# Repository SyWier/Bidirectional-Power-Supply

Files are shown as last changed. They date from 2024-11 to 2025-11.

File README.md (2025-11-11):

# Bidirectional-Power-Supply
Development of a bidirectional DC/DC power supply for battery applications.

The designed **developement** board is a **BUCK/BOOST converter**, based on the direction of the power flow. This enables us to charge a battery with voltage reduction or create an uninterrupted voltage output with voltage boost.

The developement board is easily configurable through serial communication, have test points for all the important signals and includes feedback LEDs.

## Directories
- Altium: **Altium** project of the hardware.
- CSS: **Code Composer Studio** project and other tools to flash the microcontroller



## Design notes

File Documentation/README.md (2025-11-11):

# Documentation

This folder contains the documentation for my **thesis project**. The files describe the device's specifications, development flow, and configuration. All documents are written in Hungarian.

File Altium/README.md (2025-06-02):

# Hardware

PCB designed in Altium Designer (version 24.9.1)

Specifications:
- Input: 5V, 3A 
- Output: 5V, 3A
- Battery: 3.7V, 8A
- Target voltage ripple: 0.2%
- Target current ripple: 1%
- Switching frequency: 100kHz

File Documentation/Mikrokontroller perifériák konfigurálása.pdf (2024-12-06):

# 1 Mikrokontroller perifériák programozása

## 1.1 Fejlesztő környezet

### 1.1.1 Code Composer Studio + Sysconfig

A mikrokontroller programozásához a Code Composer Studio-t használom, mely

kifejezetten a Texas Instruments által készített mikrokontrollerekhez lett készítve, így ezeket natívan

támogatja.

A Code Composer Studio ezen kívül alapértelmezetten tartalmazza a Sysconfig nevű

konfigurációs eszközt, melynek a segítségével egy grafikus felületen tudjuk konfigurálni a

perifériákat.

Help: C28x Academy (https://dev.ti.com/tirex/explore/node?node=A__AEIJm0rwIeU.2P1OBWwlaA__C28X-ACADEMY__1sbHxUB__LATEST)

### 1.1.2 C2000Ware

A mikrokontrollerekhez tartozó SDK¹
-t letölthetjük a C2000Ware telepítésével. Ez

tartalmazza a C2000-es családba tartozó mikrokontrollerek driverjeinek könyvtárát, illetve példákat

is tartalmaz a különféle mikrokontrollerekhez.

1 SDK = Software Development Kit

Mikrokontroller programozás

## 1.2 Konfiguráció sysconfig segítségével

A fejlesztés során a perifériák felprogramozásához részletes leírást találunk a

mikrokontroller adatlapjában, ahol láthatjuk, hogy mely regiszterek mely értékei mit jelentenek.

Ezek a regiszterek a fejlesztőkörnyezetben az SDK segítségével adatstruktúrákként jelennek meg.

A periféria felélesztéséhez ezeket a struktúrákat kel kitölteni a kívánt viselkedés elérésének

érdekében.

Ez a folyamat azonban hosszadalmas és sok adatlapolvasást igényel. A fejlesztés

felgyorsításának érdekében készült a sysconfig nevű konfigurációs eszköz, ahol egy grafikus

felületen be tudjuk állítani a perifériát és ez alapján kódot generál nekünk.

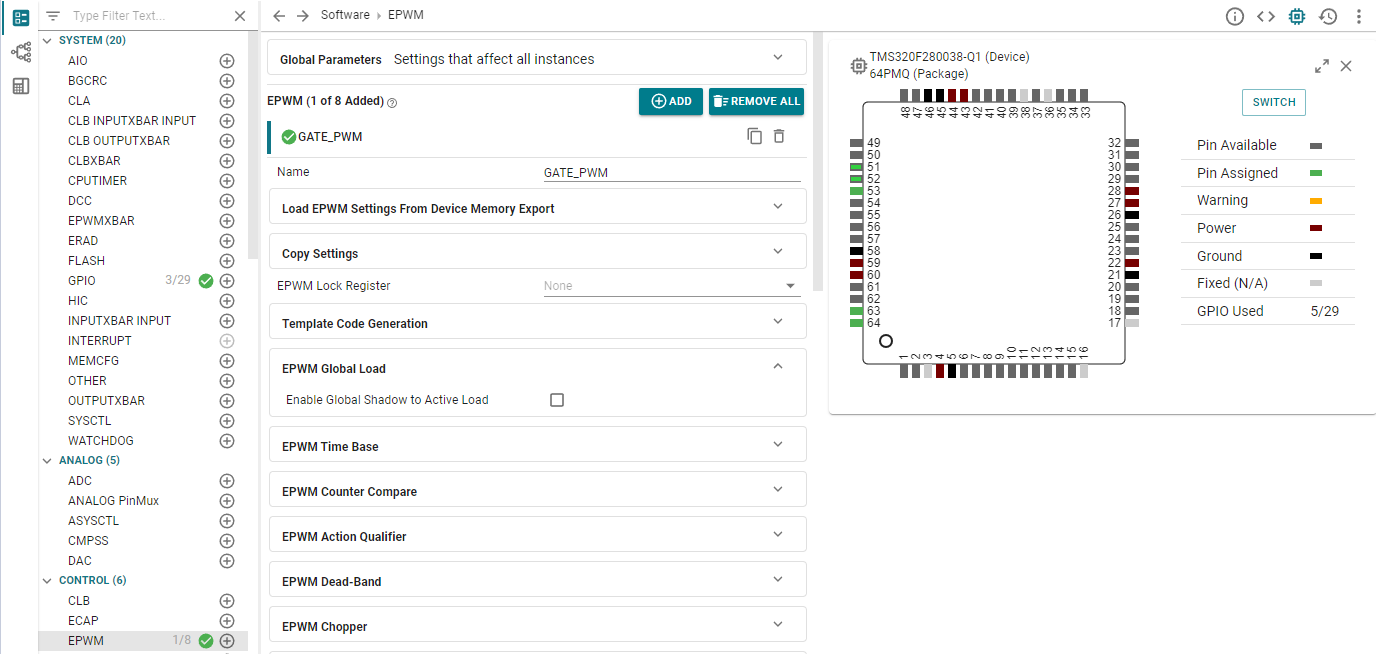
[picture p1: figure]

1-1. Sysconfig konfigurációs interfész

Source: C2000 SysConfig (spracx3.pdf) (https://www.ti.com/lit/an/spracx3/spracx3.pdf?ts=1731794783741)

## 1.3 Program feltöltése a mikrokontrollerre

### 1.3.1 Boot mode kiválasztása

Én a soros kommunikáció (SCI) mellett döntöttem, mivel ehhez elég egy USB-UART

átalakító, melyet olcsón és könnyedén a mikrokontroller mellé lehetett integrálni. A soros

kommunikáció használatához a táblázat alapján látni lehet, hogy a GPIO24-et alacsonyra kell

húzni, míg a GPIO32-őt magasra. Mivel alapértelmezetten mind a kettő GPIO értéke magas, hogy

flash-ről bootoljon, így célszerűen elég csak a GPIO24-et lehúzni alacsony szintre.

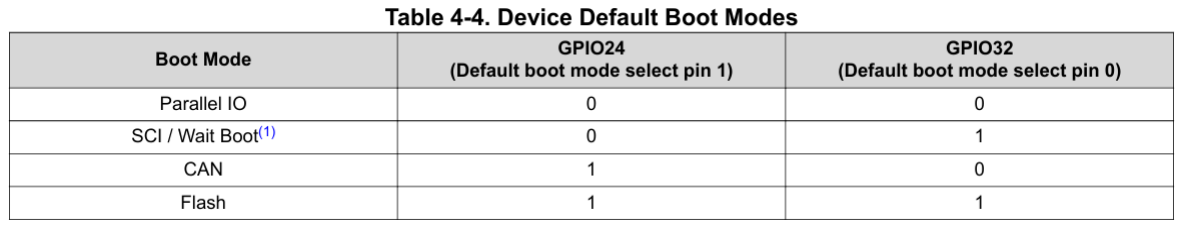
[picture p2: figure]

1-2. A mikrokontroller boot módja a kiválasztott pinek alapján

1-3. Boot 1 pin alacsonyra húzása jumper segítségével

### 1.3.2 Kód feltöltésének folyamata¹

Amikor a mikrokontroller kommunikációs perifériáit használjuk, az nagyon egyszerűen tud a

RAM-ba adatot, kódot tölteni. Viszont ez még nincs benne a nem felejtő memóriában. A két

memória közötti különbséget a flash kernel fogja áthidalni. Ez egy olyan program részlet, melyet a

kommunikáció elején a RAM-ba töltünk és a RAM-ból fogjuk futtatni. Innentől kezdve a

kommunikáció többi csomagját már a Flash memóriába fogjuk tölteni. A mikrokontrollert újraindítva

a „Flash” boot mode-ban már az így letöltött kódunk fog elindulni.

1-4. Program feltöltésének folyamatábrája

Az F280038-as mikrokontrollerhez a B típusú Flash Kernel fog tartozni, ami nem csak a

kódot fogja betölteni a flash memóriába, de még visszajelzést is ad a felhasználó fele. Ezután vár egy ’a’/’A’ karakterre. A kommunikáció megkezdésekor auto-baud segítségével autómatikusan

kiválasztódik a legmagasabb baud rate és a letöltés megkezdődik a flash memóriába.

A flash kernelt a mikrokontrollerhez tartozó driverlib-ben fogjuk megtalálni. Itt a példák

között található flash mappában megtaláljuk az SCI-hez tartozó kernel kódják, melyet lefordítva

megkapjuk a <kernel>.txt fájlt.

### 1.3.3 Alkalmazás a program feltöltéséhez

A mikrokontrollerre egy .out típusú hex fájlt kell feltölteni. Amikor CSS-ben lefordítjuk a

programunkat, a build mappában létre is fog jönni egy ilyen fájl. Ezt a fájlt a

serial_flash_programmer nevű parancssoros alkalmazásból tudjuk feltölteni a mikrokontrollerre.

Alapértelmezetten a C2000Ware SDK-ban az alábbi útvonalon lehet megtalálni:

C2000Ware_x_xx_xx_xx > utilities > flash_programmers > serial_flash_programmer

Az alkalmazás számára meg kell mondanunk minden szükséges paramétert ami

szükséges a mikrokontroller programozásához:

- -d <device>: The name of the device to connect and load to: F28003x
- -k <file>: The file name for the CPU1 flash kernel: flash_kernel_ex3_sci_flash_kernel.txt
- -a <file>: The application file name to download: UPS.out
- -p COM<num>: Set the COM port to be used for communications: eg. COM10
- -b <num>: Set the baud rate for the COM port: eg. 115200

A teljes paraméter lista így fog kinézni:

serial_flash_programmer.exe -d f28003x -k flash_kernel_ex3_sci_flash_kernel.txt -a UPS.hex

-p COM10 -b 115200

## 1.4 PWM jel előállítása

Az ePWM, vagyis enchanced pulse width modulator (impulzus-szélesség moduláció)

segítségével négyszögjeleket állíthatunk elő a buck-boost konverterünkben található MOSFET-ek

vezérlésére. A mikrokontrolleren belül ezen a perifériák párban állnak rendelkezésre (A modul és B

modul), melyek egymásnak az inverz jelét állítják elő. Ennek a segítségével könnyedén

vezérelhetjük az átalakítónkat.

Az ePWM generátor egy számláló segítségével állítja elő a négyszögjelünket. A számláló

minden órajel ciklusra megváltoztatja az értékét (ez lehet felfelé, lefelé, illetve fel-le számlálás. A

számláló maximális értékét meghatározva kapjuk meg a pulzusunk periódus idejét. A kitöltési

tényező meghatározásához szükségünk van egy komperálási szintre is, melynek az értéke esetén

meg tudjuk változtatni a jelünket.

Az ePWM-ből képesek vagyunk különböző eseményeket is elindítani, például a periódus

elérésekor, a számláló null értéke esetén, vagy valamely komperálási szint elérésekor. Ez

számunkra hasznos lesz az analóg mintavételezéshez, hogy mindig a jel közepén vegyünk mintát.

Source: C2000 ePWM Developer’s Guide (sprad12a.pdf) (https://www.ti.com/lit/an/sprad12a/sprad12a.pdf?ts=1732109075007)

### 1.4.1 ePWM modul

### 1.4.1.1 Frekvencia beállítása

A PWM jel előállításához szükségünk lesz a periódusidő kiszámolására is. Ennek a

kiszámolásához szükségünk van az ePWM modul órajelének meghatározására. Ez jelen esetben,

mivel az órajelünket nem osztjuk le, meg fog egyezni a rendszer órajelével (SYSCLK), vagyis

120MHz lesz.

Ez alapján a paraméterek a következőek:

TBCLK² = 120MHz => TTBCLK = 8.33ns

Határozzuk meg a MOSFET-ek kapcsolási sebességét (100kHz):

TPWM =

1

FPWM

=

1
100kHz = 10us

A számláló a TBPRD³ értékig fog számolni, így a periódusidő is ettől fog függeni. Fel vagy

lefelé számolás esetén más képleteket kell figyelembe vennünk, mint fel és lefelé számolás esetén,

mivel olyankor kétszer olyan hosszú a tartomány.

2 TBCLK = time-base clock
3 TBPRD = time-base period

Fel vagy lefelé számolás:

### TPWM = (TBPRD + 1)TTBCLK

Fel és lefelé számolás:

### TPWM = 2 ∗ TBPRD ∗ TTBCLK

A jelünket szeretnénk mintavételezni is, amit érdemes a jel közepénél megtenni. Erre

érdemes háromszögjelet választani, vagyis felfelé és lefelé számolni, mivel ilyenkor tudunk a

számláló ZRO⁴ és PRD⁵ értékénél mintavételezést indítani. Ez azért nagyon hasznos nekünk, mivel

a CMPA érték megváltoztatása, vagyis a kitöltési tényező megváltoztatása esetén is a jel közepénél

fogunk mintát venni, így azt nem kell megváltoztatni.

TBPRD =

TPWM

2 ∗ TTBCLK

=

10us
2 ∗ 8.33ns

= 600

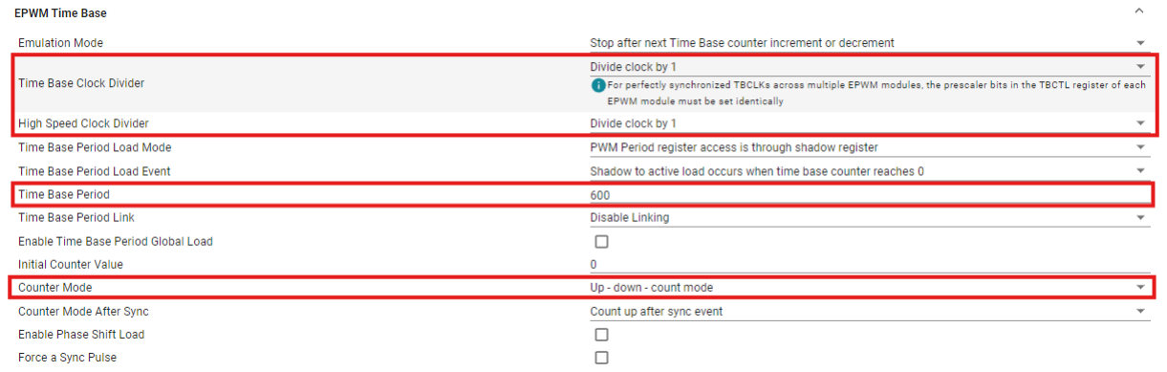
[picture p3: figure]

Frekvencia beállítására sysconfig segítségével.

### 1.4.1.2 Szinkonizáció a PWM jelek között

Mivel a mikrokontroller teljesítményelektronikák vezérlésére készült, így több beépített

funkciót is tartalmaz ezek támogatására. Egyik ilyen funkció, hogy tudjuk szinkronizálni a jeleinket,

ami akkor nagyon lényeges, ha a jeleink között fáziseltérés van, amit tartani is szeretnénk (például

egy háromfázisú inverternél). Jelen esetben csak egy darab PWM jelünk van, így csak arra kell

figyelni, hogy ne várjon szinkronizációs inputra.

4 ZRO = Zero
5 PRD = Period

### 1.4.1.3 Kitöltési tényező beállítása

A kitöltési tényező (duty cycle) meghatározásához a komparátor értékét kell beállítanunk.

Például ha 5V-ból 3.7V-ot szeretnénk előállítani, ahhoz 74%-os kitöltési tényezőre lesz szükségünk. Állítsuk elő a jelünket úgy, hogy alapból alacsony az értéke, de a komparátor két értéke között

(vagyis amíg nagyobb a számláló értéke, mint COMPA), addig magas a PWM kimenete.

A kitöltési tényező kiszámítása:

D =

ton
T

= 1−

COMPA
TBPRD

⇒

COMPA = (1 −D) ∗ TBPRD = 156

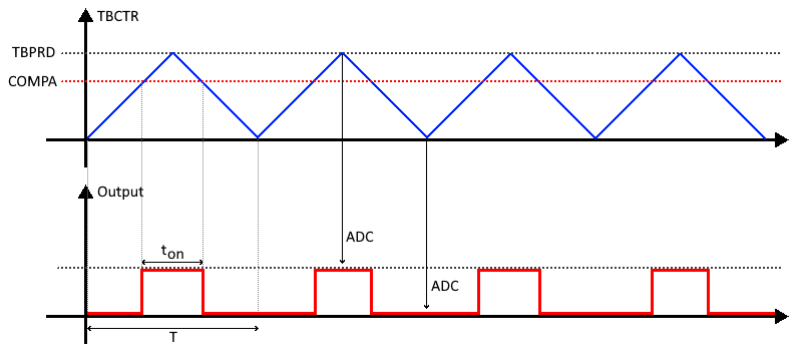
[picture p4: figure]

PWM jel előállítása és mintavételezés

A Shadow regiszter engedélyezésére azért van szükség, hogy ha a későbbiekben majd

módosítani szeretnénk CMPA értékét, hogy más legyen a kitöltési tényező, akkor azt majd itt fogjuk

tudni megtenni. Azért érdemes Shadow regiszteren keresztül betölteni, mert ha menet közben

állítanánk, meg van rá az esély, hogy átugorjuk a számláló értékét, ezzel a kimenetünkön kihagyva

egy jelet és torzítva a PWM-et. A Shadow regisztert a számláló null értékekor fogjuk betölteni.

### 1.4.1.4 Action Qualifier

Ahhoz, hogy előállítsuk a PWM jelet, meg kell mondanunk a jelünknek, hogy milyen

esemény esetén mit csináljon. A mi esetünkben amikor felfelé számlálunk ePWMxA-val, amikor eléri a COMPA értékét, akkor legyen magas a kimeneti jel. Amikor lefelé számolva éri el COMPA

értékét, akkor pedig legyen alacsony a kimeneti jel.

Ezt a beállítást csak ePWMxA esetén kell megtennünk, mivel ePWMxB-t a Deadband

Submodule segítségével fogjuk előállítani, olyan módon, hogy Active High Complementary jel

legyen, aminek a forrása ePWMxA lesz.

### 1.4.2 Deadband (DB) Submodule

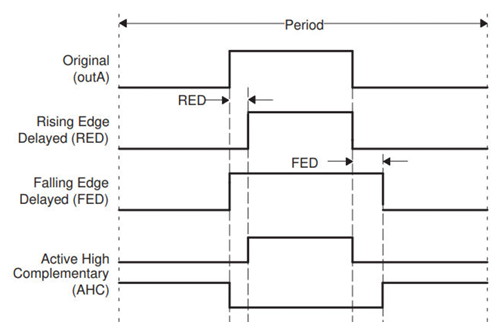
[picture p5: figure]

A deadband⁶ segítségével

egy holtsávot határozhatunk meg az

A és B ePWM modulok között. Ez

azért nagyon fontos, mivel a

MOSFET-nek váltás esetén kell még

egy kis idő, hogy lezárjanak. Ha ezt

az időt nem adjuk meg nekik, a VDD

és GND vonalak között rövidzár

alakul ki, mivel mindkét MOSFET

nyitva van. Ezt a jelenséget

keresztezési áramnak hívjuk.

### 1.4.2.1 Deadband méretezése

A MOSFET teljes lezárásához meg kell várnunk a tf „fall time”-ot (és ennél érdemes egy

kicsit több idővel számolni. Az áramkörhöz választott MOSFET esetén: tf = 20.2ns. Ez alapján a

„dead time”-ot ennél jóval nagyobbra választom, 100ns-ra, hogy biztosan zárva legyen már a

MOSFET.

A jeleket „Active High Complementary” (AHC) módban kell használni, vagyis az aktív jel

előtt és után is lesz egy olyan állapot, amikor egyik jel sem aktív. Ezt úgy tudjuk elérni, hogy az

aktív jel várakozik amikor felfutna az éle (RED = Rising Edge Delay), míg az invertált jel pedig az

aktív jel lefutó éle esetén várakozik (FED = Falling Edge Delay).

6 Deadband = holtidő

A RED, illetve FED értékeket az alábbi képletek alapján lehet kiszámolni:

RED = DBRED ∗ TTBCLK ⇒

DBRED =

RED

TTBCLK

=

100ns
8.33ns

→ DBRED = 12

A „falling edge delay value” értéke meg fog egyezni a DBRED értékével.

A Dead-Band modul felkonfigurálásának megkönnyítésére be tudjuk tölteni a gyakori

konfigurációkat. Itt én az Active High Complementary opciót választottam, ami kiválasztotta

megfelelő opciókat, így nekem már csak a kívánt késleltetési időket kellett beírnom.

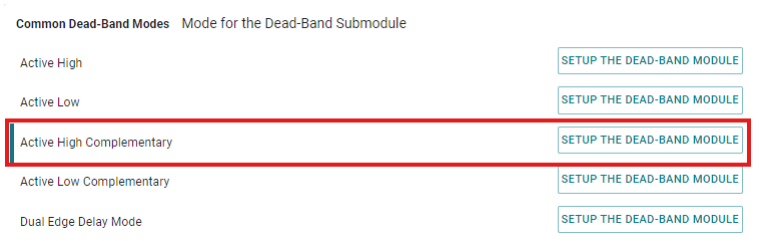
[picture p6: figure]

Gyakori Dead-Band konfigurációk betöltése.

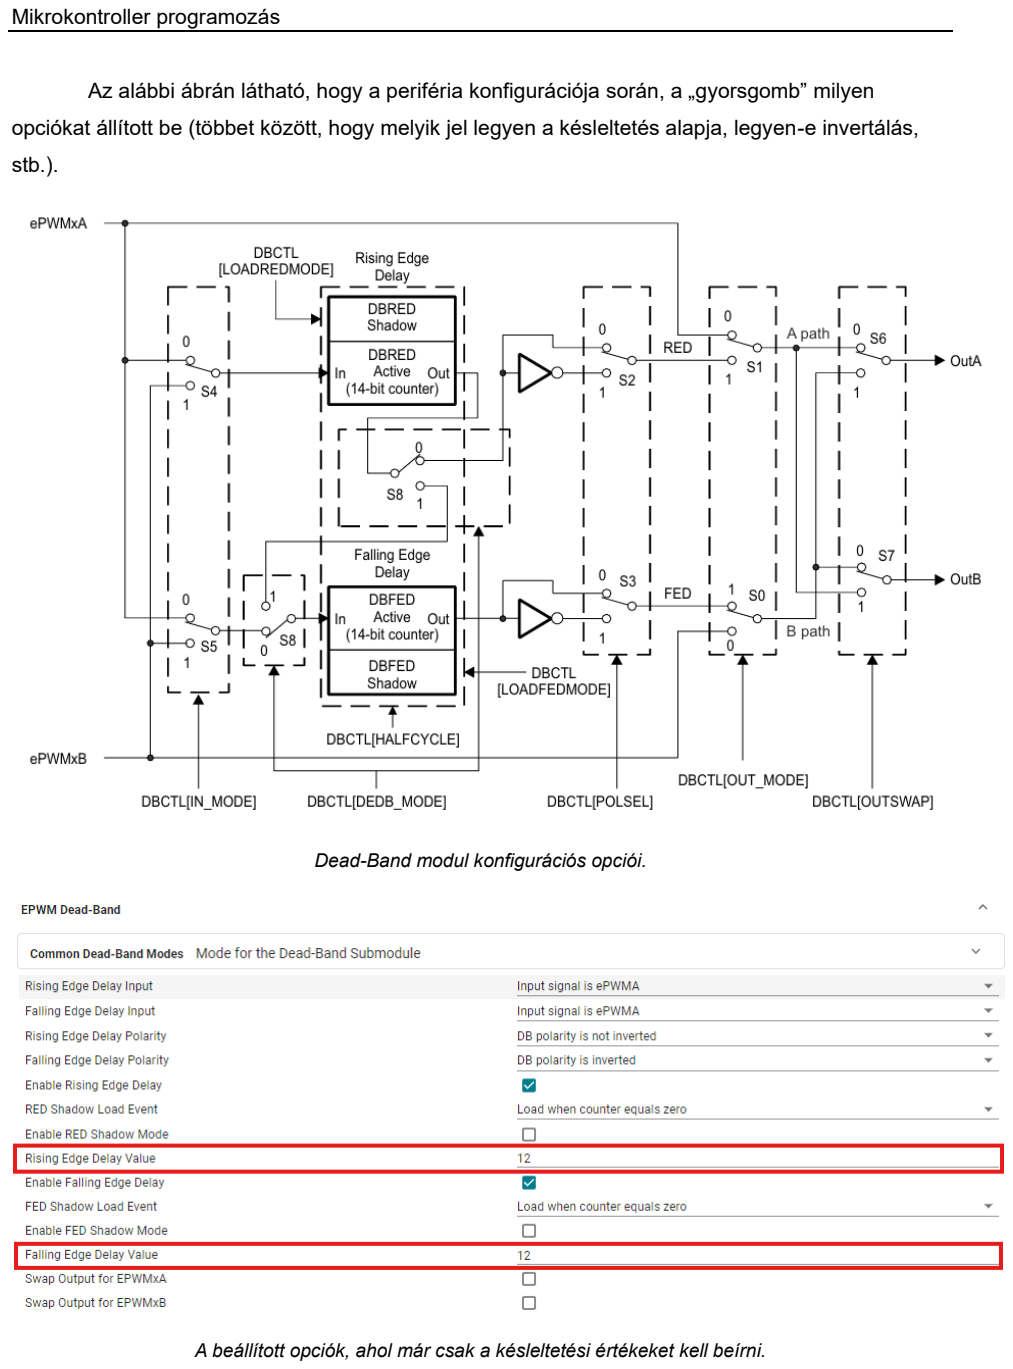
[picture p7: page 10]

Az alábbi ábrán látható, hogy a periféria konfigurációja során, a „gyorsgomb” milyen

opciókat állított be (többet között, hogy melyik jel legyen a késleltetés alapja, legyen-e invertálás,

stb.).

Dead-Band modul konfigurációs opciói.

A beállított opciók, ahol már csak a késleltetési értékeket kell beírni.

## 1.5 PWM hibavédelem

### 1.5.1 Trip-Zone (TZ) Submodule

Az ePWM esetén lehetőség van Trip-Zone-ok („leoldási zónák”) meghatározására. Ez egy

olyan védelem, ahol egy hiba vagy esemény hatására a PWM modul egy meghatározott állapotba

lép. A Trip-Zone aktíválására lehetőségünk van digitális komperátor használatára.

A Trip-Zone működése lehet Cycle-By-Cycle, ilyenkor aktiválódáskor a kimenetek a kívánt

állapotban vannak, viszont ZRO vagy PRD esetén újból engedélyezve vannak. A másik fajta

működés a One-Shot, mely csak egyszer aktiválódik, ahhoz, hogy a PWM folytassa működését

szoftveresen engedélyeznünk kell.

A panelhez a One-Shot működést szeretnénk, hibás működés esetén nem szeretnénk,

hogy az áramkör újból működésbe lépjen.

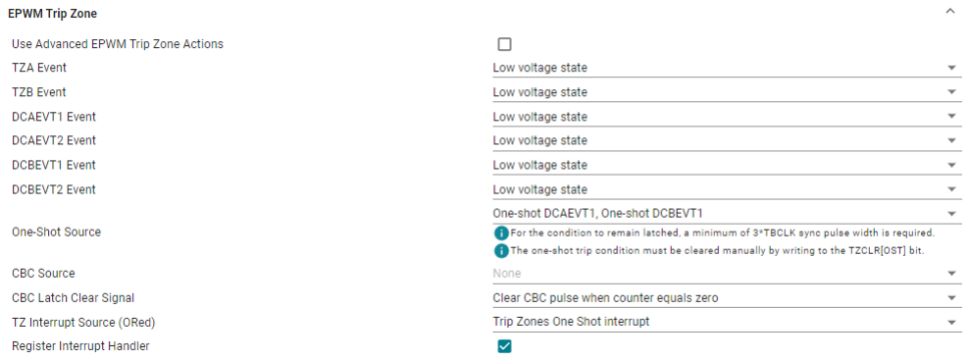
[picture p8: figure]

Trip-Zone aktiválódásakor alacsony értéket vesznek fel a kimenetek.

### 1.5.2 Digital Compare (DC) Submodule

### 1.5.2.1 Digitális komparátor

Egy digitális komperátor belső 12 bites analóg referenciáját hasonlítjuk össze egy analóg

bemenettel. Az összehasonlítás eredményeképpen az EPWMxA és EPWMxB modulokat az

általunk meghatározott állapotba vihetjük. Ez egy fontos védelem, melynek a segítségével

hardveres alapon a hiba bekövetkeztével rögtön reagálhatunk rá, a szoftver aktuális állapotától

függetlenül.

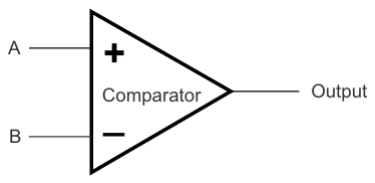
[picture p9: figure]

A digitális komperátor kimenete magas, ha a komperátor pozitív bemenetén nagyobb a

feszültség, mint a negatív bemenetén. A védelmet úgy tudjuk megvalósítani, hogy kiszámoljuk,

mely feszültség esetén van overvoltage vagy undervoltage. Ennek az értéknek megfelelő

referencia feszültséget kötünk a komparátor negatív bemenetére és ha a pozitív bemenetén

magasabb a feszültség, akkor a komparátor kimenete magas értéket vesz fel. Undervoltage esetén

a komparátor kimenetét invertálnunk kell. A komparátor magas értéke esetén aktiválódik a Trip-

Zone.

Egy Digital Compare submodule-ban két komparátor található, egy High és egy Low.

Ezeket egy submodule használatával tudjuk ellenőrizni az over- és az undervoltage-ot.

A komparátor használatához meg kell határoznunk, hogy melyik komparátor tartozik az

áram mérésére szolgáló analóg pinhez. Ezt az „Analog Subsystem Block Diagram”-ja alapján

könnyedén meg tudjuk tenni:

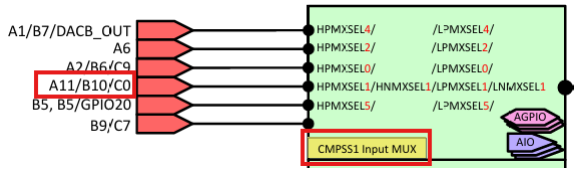
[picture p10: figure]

Analog Subsystem Block Diagram

Megfelelő komparátor kiválasztása

### 1.5.2.2 Komparátor méretezése

Az áramkör alap állapotban normális működés esetén 6A áramnál nem fogyaszt többet.

Ennél csak akkor lehet magasabb az áramfelvétel, ha az akkumulátor feszültsége nagyon

alacsony (ami már a kapacitásának a legvége és ilyenkor az akkumulátor használata már káros)

vagy pedig ha hiba lépett fel az áramkörben.

Az áramkör maximálisan 8A áram felvételére van méretezve, mikor már az akkumulátor feszültsége nagyon alacsony (2.5V), melyet nem szeretnénk elérni. Így a korlátot 7A-re

méretezzük.

Az árammérő referencia feszültsége 1.65V, és a teljes tartományban (-8A … 8A) -1.6V és

1.6V között változik az árammérő feszültsége.

Linearizált képlet a feszültség kiszámolására az áram függvényében:

Vcur+ = Vref + 0.2 ∗ I = 1.65V + 0.2 ∗ 7A = 3. 05V = DACOUT+

Vcur− = Vref + 0.2 ∗ I = 1.65V − 0.2 ∗ 7A = 0. 25V = DACOUT−

Referencia feszültség DAC⁷ értéke:

DACOUT =

DACVALA ∗ DACREF
4096

⇒

DACVALA+ =

4096 ∗ DACOUT
DACREF =

4096 ∗ 3.05V
3.3V = 3785

DACVALA− =

4096 ∗ DACOUT
DACREF =

4096 ∗ 0.25V
3.3V = 310

7 DAC = Digital-Analog Converter

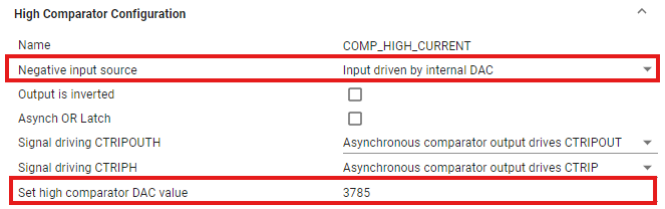
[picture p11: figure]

High comparator beállítása

A low komparátor esetén ügyeljünk arra, hogy a kimenet invertálva legyen.

Ezen kívül figyeljünk, hogy a DAC referencia feszültsége VDDA (3.3V) legyen.

VDDA referencia feszültség

### 1.5.2.3 Digital Filter

A digitális komparátorunknak lehetőségünk van a kimenetének a megszűrésére. Ezzel

elkerülhetjük, hogy egy zaj okozta hibás mérés miatt leálljon az egész áramkör.

Egyrészt szűrve van a magas frekvenciás rajoztól, mivel csak minden n-edik órajelre

veszünk intát. Másrészt a FIFO-ban található magas értékeknek többségben kell lenniük.

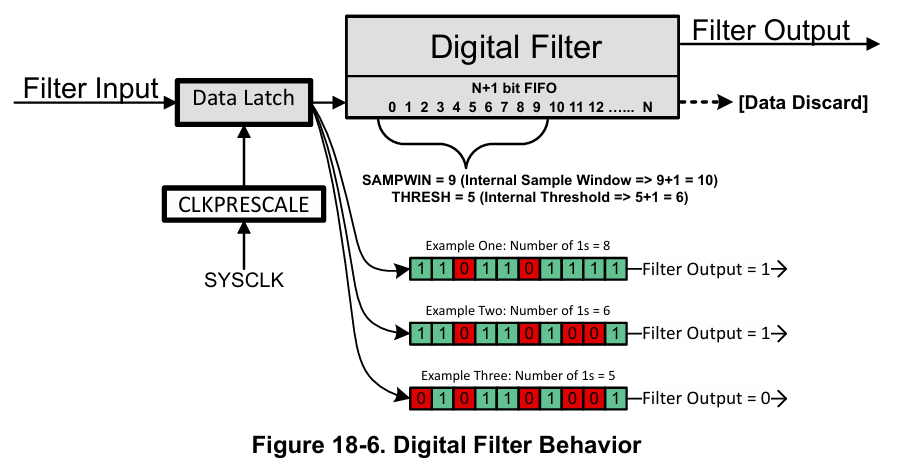
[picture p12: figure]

A filtert kezdetben töröljük, hogy inicializálás esetén ne menjünk rögtön hibás állapotba. A

prescale 0, ami azt jelenti, hogy minden órajelre mintát veszünk. Illetve a FIFO mérete 9 lesz,

amiből legalább 5 darab 1-esnek kell lennie, ahhoz hogy aktiválódjon a komparátor kimenete.

Ez azt jelenti, hogy 9/120MHz = 75ns késleltetést visz be a rendszerbe, viszont ellenállóbb lesz a

zajokkal szemben.

Digitális filter beállítása.

### 1.5.3 ePWM X-BAR

A digitális komparátor beállítása után szükségünk van, hogy a jelét a Trip-Zone-hoz

vezessük. Mivel alapértelmezetten nincsen közvetlen összeköttetés közöttük, ezért saját

magunknak kell meghatároznunk azt. Ezt az ePWM X-BAR segítségével tudjuk megtenni. Ahhoz,

hogy ezt konfigurálni tudjuk meg kell határoznunk a jelünket.

A komparátor oldaláról meg kell keresnünk, annak a kimenetét.

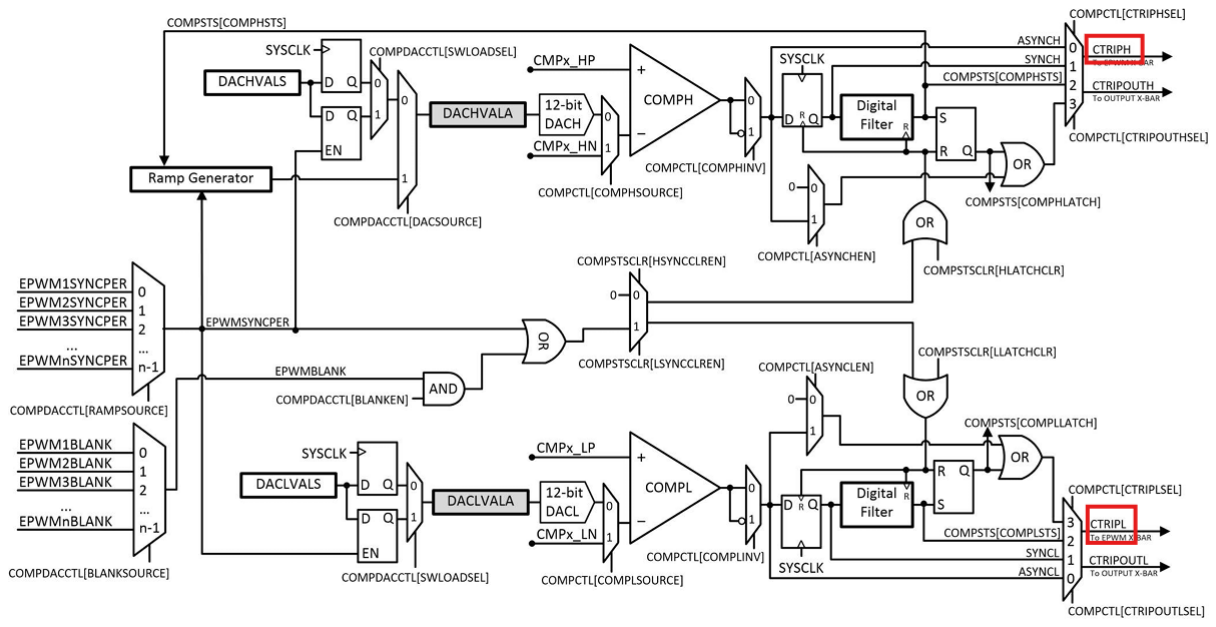
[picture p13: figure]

High and Low comparator output.

Ezt a jelet az ePWM X-BAR Mux konfigurációs táblázatban megkeresve láthatjuk, hogy mi lesz a

Mux értéke. A táblázat alapján látható, hogy a high és a low komparátor kimenetét be lehet

egyszerre kötni.

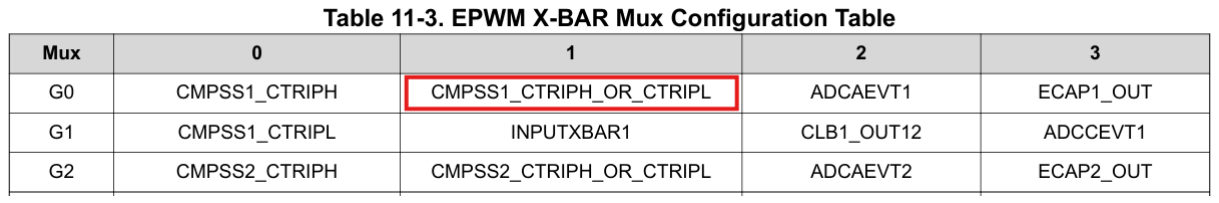
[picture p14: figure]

ePWM X-BAR Mux Configuration Table

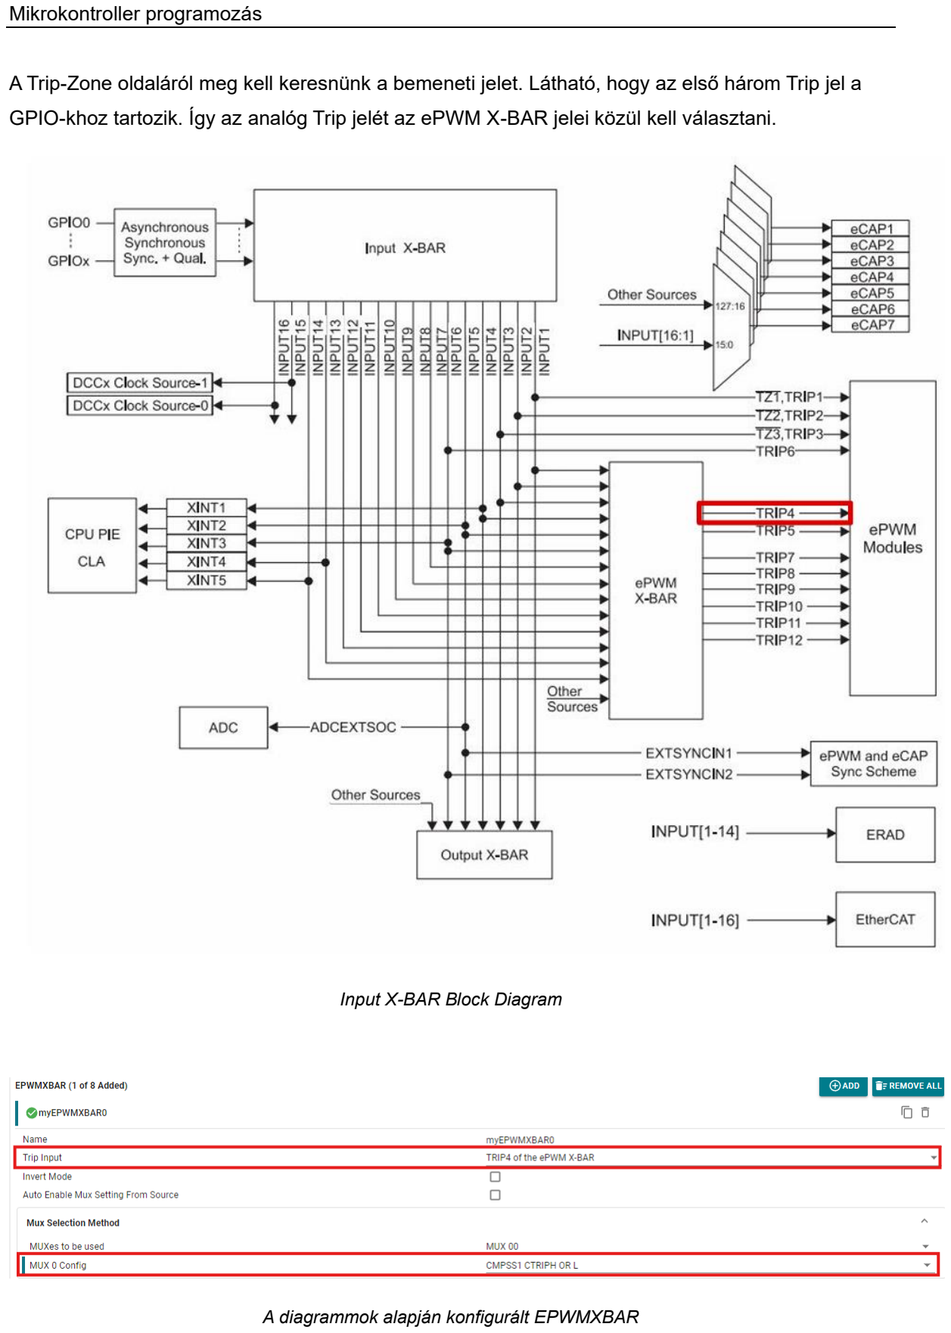
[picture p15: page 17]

A Trip-Zone oldaláról meg kell keresnünk a bemeneti jelet. Látható, hogy az első három Trip jel a GPIO-khoz tartozik. Így az analóg Trip jelét az ePWM X-BAR jelei közül kell választani.

Input X-BAR Block Diagram

A diagrammok alapján konfigurált EPWMXBAR

Miután már összekötöttük a DC jelét a Trip-Zone-al, az ePWM digital compare viselkedését

be tudjuk állítani. A mikrokontroller dokumentációjában olvashatjuk, hogy One-Shot eseményt csak

az DCxEVT1-es event válthat ki. Mivel egy DCxEVT1 event csak egy komparátor kimenetét tudja

fogadni, így a DCAEVT1 és a DCBEVT1 eventeket is használjuk.

20.9.2 Operational Highlights for the Trip-Zone Submodule

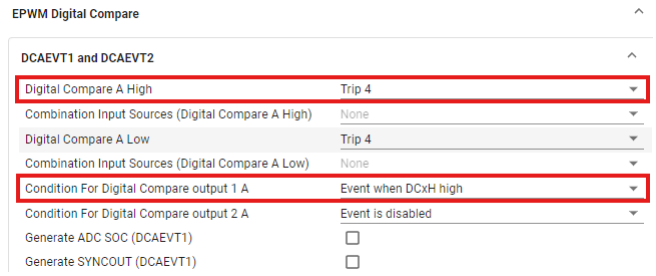
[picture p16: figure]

Trip-Zone bemenet és kiváltó feltétel beállítása. B event esetén a kiváltó feltétel a low komparátor.

## 1.6 Analóg mintavételezés

### 1.6.1 Analóg referencia feszültség

Az analóg mintavételezéshez szükséges, hogy megadjuk az átalakítók referencia

feszültségét. A mért feszültségek a 3.3V-os tartományra vannak méretezve, így a referencia

feszültséget is ennek megfelelően kell választani.

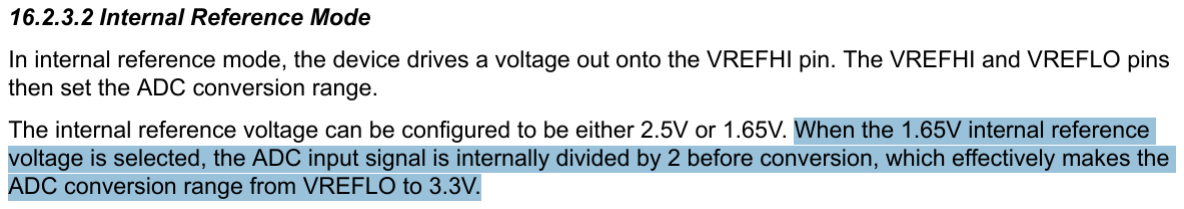
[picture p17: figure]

Internal Reference Mode

A mikrokontroller adatlapja alapján, ha belső 3.3V-os referencia feszültséget szeretnénk, akkor az

1.65V-os referenciát kell választani, mely esetén a mért jel is le van osztva 2-vel.

### 1.6.2 Event-Trigger (ET) Submodule

Az Event-Trigger modul segítségével a TB⁸

, CC⁹ és DC¹⁰ eseményeinek hatására

megszakítást (IT) vagy analóg-digitál konverziót (ADC) tudunk indítani.

A Buck-Boost konverter megvalósításához érdemes lesz a számlálót ZRO, illetve PRD

érték esetén indítani analóg-digitál konverziót, ekkor a PWM jelek közepén fogunk mintavételezni,

amikor már (feltehetőleg) lefutottak a tranziensek.

A rendszeres mintavétel kulcsfontosságú az átalakító megvalósításához, hiszen ez lesz a

visszacsatolásunk a szabályzást illetően.

8 TB = Time-Base submodule
9 CC = Counter-Compare submodule 10 DC = Digital Compare submodule

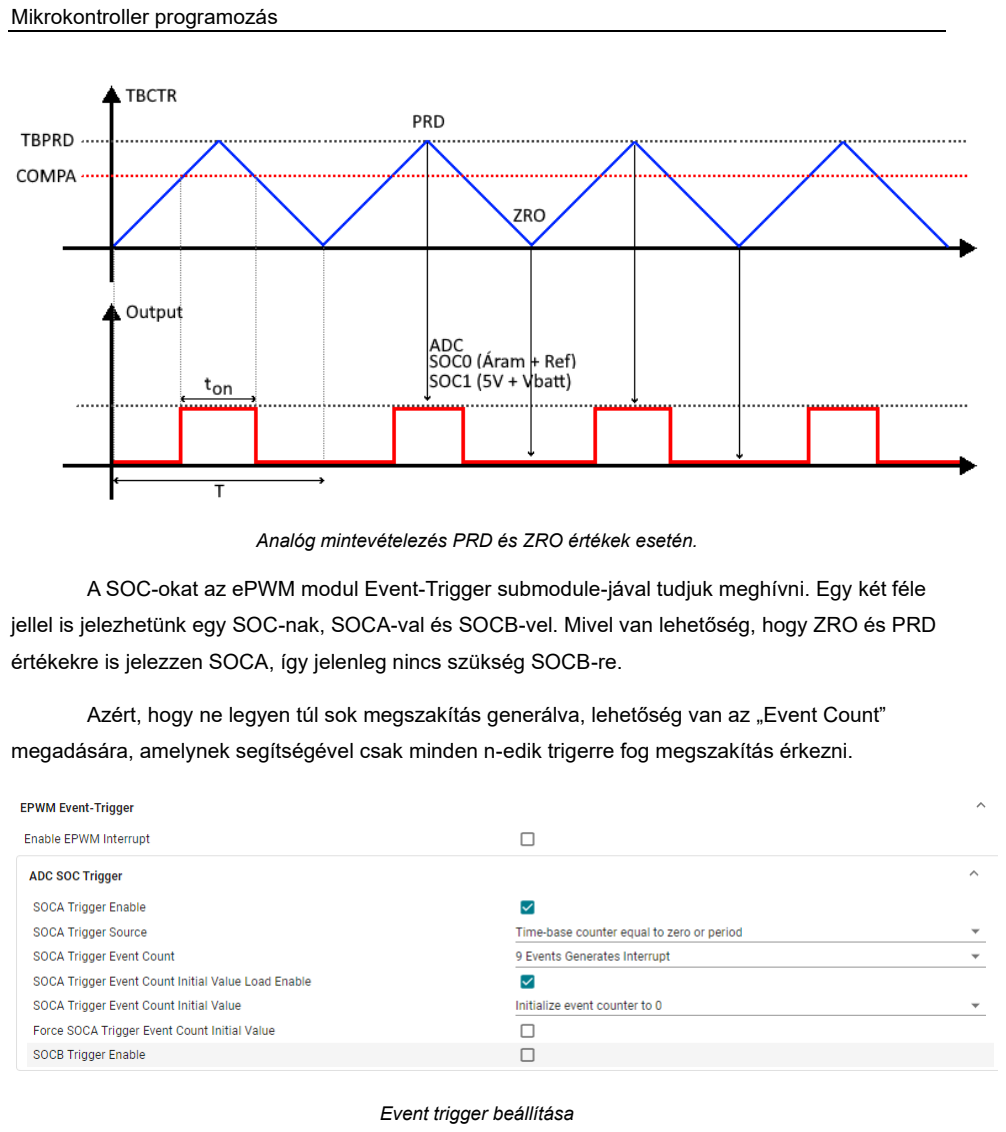
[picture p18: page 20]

Analóg mintevételezés PRD és ZRO értékek esetén.

A SOC-okat az ePWM modul Event-Trigger submodule-jával tudjuk meghívni. Egy két féle

jellel is jelezhetünk egy SOC-nak, SOCA-val és SOCB-vel. Mivel van lehetőség, hogy ZRO és PRD

értékekre is jelezzen SOCA, így jelenleg nincs szükség SOCB-re.

Azért, hogy ne legyen túl sok megszakítás generálva, lehetőség van az „Event Count”

megadására, amelynek segítségével csak minden n-edik trigerre fog megszakítás érkezni.

Event trigger beállítása

### 1.6.3 Start-Of-Operation (SOC)

### 1.6.3.1 SOC konfiguráció

Az Analóg-Digitál Konverterek működésének egyik alapköve a SOC rendszer. Mindegyik

ADC külön SOC-okkal rendelkezik, és egy SOC-ban a következő mezők találhatóak: analóg pin,

mintavételi idő, trigger feltétel, eredmény.

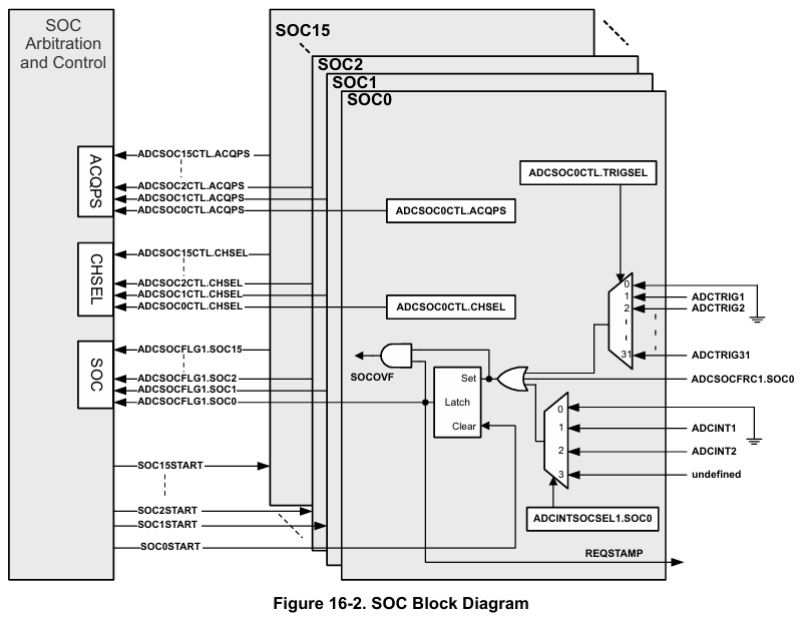
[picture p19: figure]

Mivel a mikrokontrollerben 3 darab ADC van és mi 4 különböző analóg jelet akarunk

mintavételezni, így nem tudunk minden jelnek külön ADC-t adni, hanem egymás között kell

felosztani őket. Ha egy ADC-nek több SOC-ot is megadunk, akkor Round-Robin alapon kerül

felosztásra (de akár prioritással is lehet őket). A konverzió ideje sokkal gyorsabb, mint a PWM jel

periódusideje, így ez számunkra nem lesz meghatározó, viszont azért, hogy a megszakítások

hívásakor mindig készen álljanak az eredmények, így SOC0-nak adom a prioritást, míg SOC1 fogja

hívni az IT-t.

SOC prioritás beállítása.

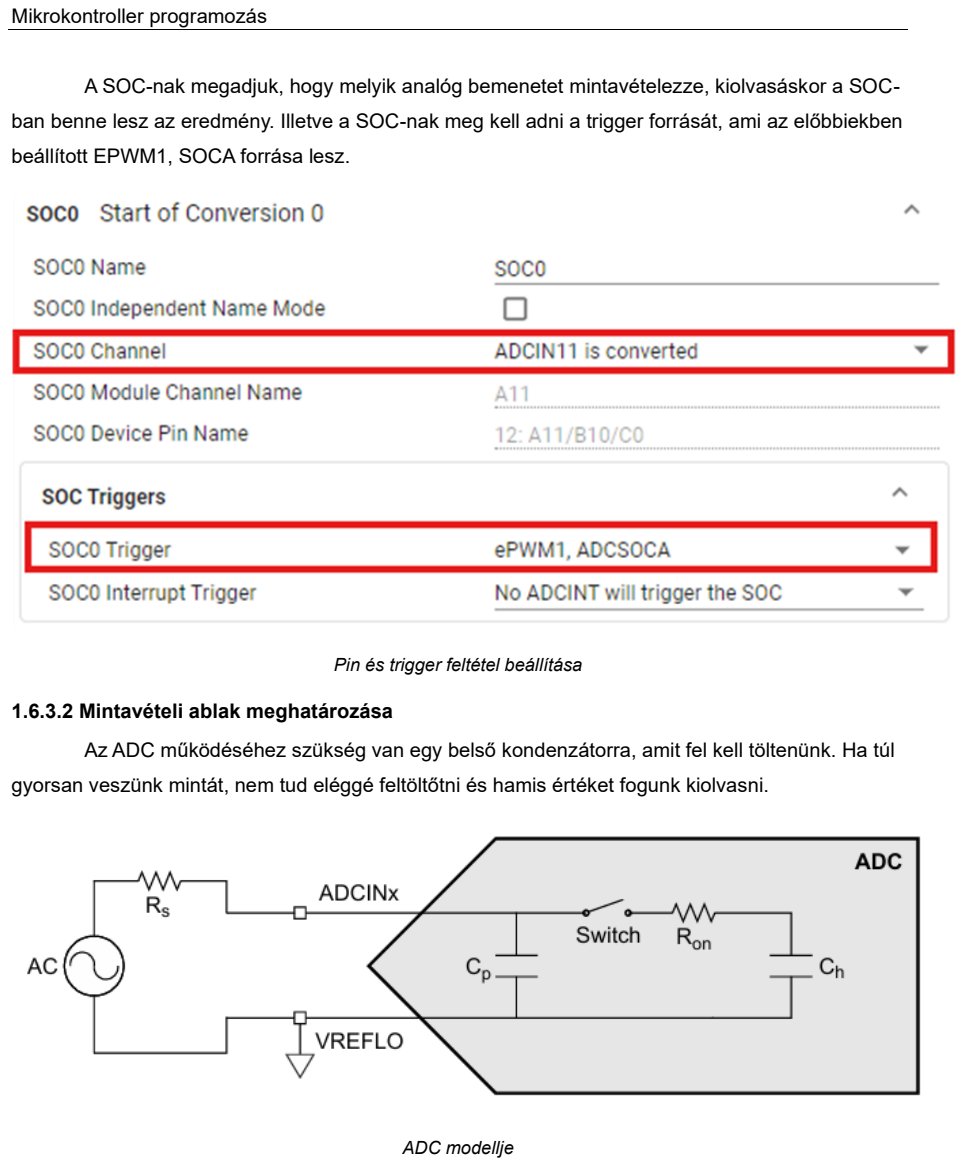
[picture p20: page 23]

A SOC-nak megadjuk, hogy melyik analóg bemenetet mintavételezze, kiolvasáskor a SOC-

ban benne lesz az eredmény. Illetve a SOC-nak meg kell adni a trigger forrását, ami az előbbiekben

beállított EPWM1, SOCA forrása lesz.

Pin és trigger feltétel beállítása

### 1.6.3.2 Mintavételi ablak meghatározása

Az ADC működéséhez szükség van egy belső kondenzátorra, amit fel kell töltenünk. Ha túl

gyorsan veszünk mintát, nem tud eléggé feltöltőtni és hamis értéket fogunk kiolvasni.

ADC modellje

A mintavételhez szükség van a Ch kapacitás feltöltésére, ami a vele sorosan kapcsolt

ellenállás lassít. Ugyanakkor a bemenetre kapcsolt kondenzátor segít, mivel tud töltéseket

biztosítani.

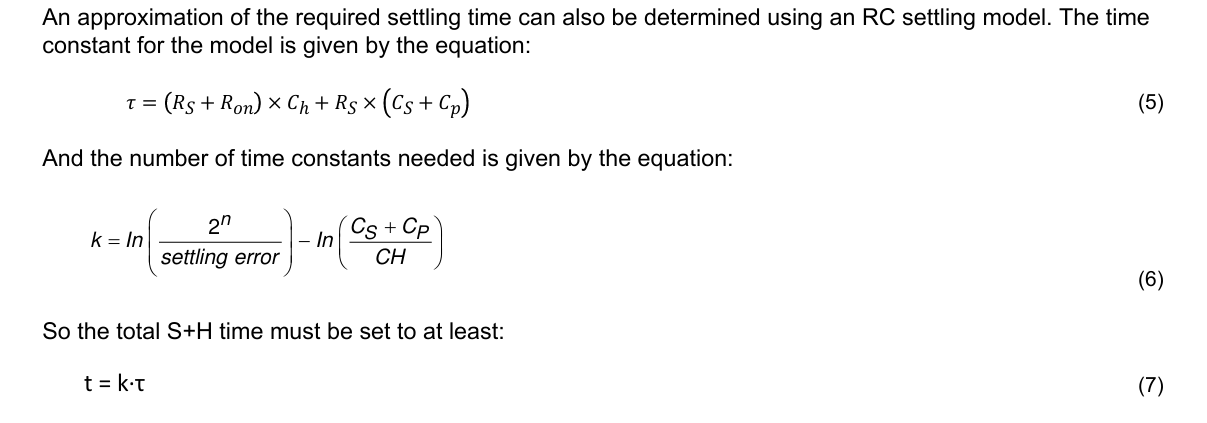
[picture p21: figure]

Rs-t a bemeneten lévő ellenállás osztóból meg tudjuk határozni: Rs = 3.3k x 4.7k = 1940 Ohm

A bemeneten egy Cs = 47nF értékű kondenzátor van.

Az adatlap alapján ismerjük a többi értéket:

Ron = 860 Ohm

Ch = 7.5pF

Cp = 13pF

A fenti egyenletbe behelyettesítve Tau = 60.77ns.

A végértéket ¼ LSB-re közelítsük meg, tehát a settling error legyen 1/4.

k = 9.7 – 8.7 = 1

Tehát legalább 60.77ns-ot kell várni.

A sample window legkisebb értéke 9, ami 75ns-nek felel meg, így ez nekünk jó is lesz.

### 1.6.3.3 ADC megszakítás

Engedélyezzük a megszakításokat, hogy szoftverből is elérhessük. A megszakítást SOC1

indítsa, mert akkor már lefutott mind a kettő konverzió.

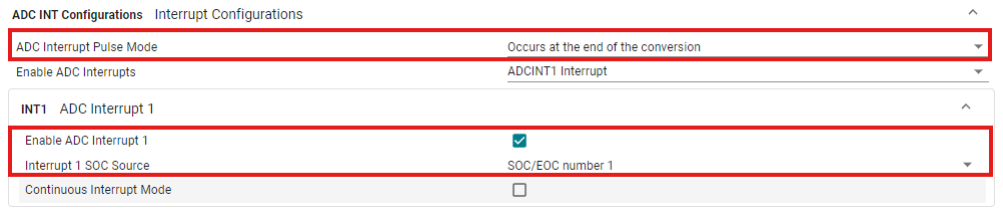
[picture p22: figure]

Beállítjuk a megszakítást.

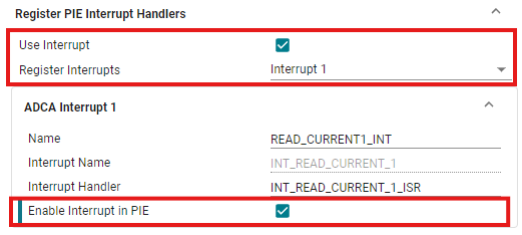
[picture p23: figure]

A megszakítást engedélyezzük a megszakítás kezelőben is.

## 1.7 Timer

A fő ciklusban lassú függvények is lefutnak. Viszont, ha nem lenne semmi korlát rajtuk,

akkor az idő nagy részében a CPU velük foglalkozna, miközben lehetséges, hogy van másik fontos

feladat is, amit végre kellene hajtani.

Erre a feladatra jelent megoldást egy időzítő használata. Az időzítő segítségével meg

tudjuk oldani, hogy a lassú program részletünk csak adott időközönként fusson le.

A timer modult ezen kívül, mint ahogy a nevéből is adódik, időzítésre is tudjuk használni. Az

időzítő által generált megszakításokat számolva nem blokkoló módon várakozhatunk. Az időzítő

beállításához meg kell adnunk, hogy hány órajelig számoljon. Jelen esetben nem lesz leosztva a

CPU óra jele, így a képlet a következőképpen alakul:

TTIM = TCPU ∗ N ⇒ N = TTIM ∗ fCPU = 1ms ∗ 120MHz = 120000

Tehát az időzítőnek 120000 órajelig kell várnia minden megszakítás generálás között.

1-5.Időzítő beállítása

Mivel a TIMER1

megszakítása közvetlenül van

bekötve a CPU-ba, így a

megszakításkezelő

függvényünkben már nem kell

külön törölni a megszakítás flag-

jét.

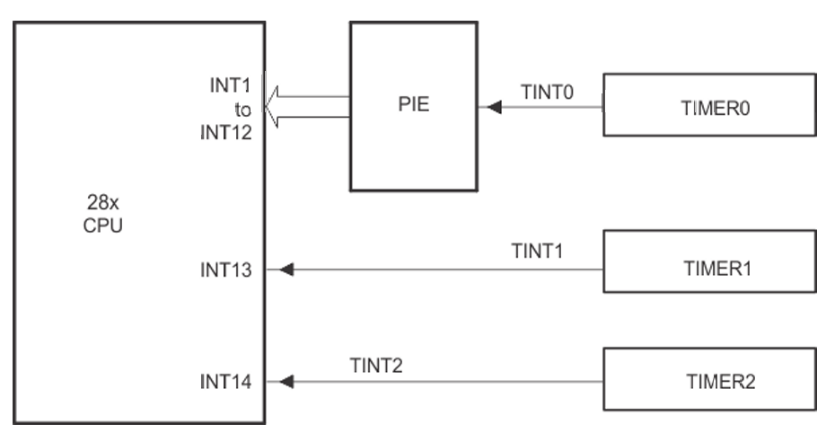
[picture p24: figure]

1-6. Időzítő megszakítások bekötése a CPU-ba

# 2 Referenciák

1 Serial Flash Programming of C2000™ Microcontrollers (sprabv4h.pdf) (https://www.ti.com/lit/an/sprabv4h/sprabv4h.pdf?ts=1731573510653)

C2000™SoftwareControlledFirmwareUpdateProcess (spracn1.pdf) (https://www.ti.com/lit/an/spracn1/spracn1.pdf?ts=1731590255089)

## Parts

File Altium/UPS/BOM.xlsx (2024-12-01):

Comment | Description | Designator | Footprint | LibRef | Quantity | Supplier | Supplier Part Number
47pF | Ceramic Capacitor, Multilayer, Ceramic, 100V, 5% +Tol, 5% -Tol, C0G, 30ppm/Cel TC, 0.000047uF, Surface Mount, 0603 | C1, C2, C35, C36, C37 | CAP0603 | 47pF | 5 | Mouser | 80-C0603C470J1G
470pF | Ceramic Capacitor, Multilayer, Ceramic, 250V, 5% +Tol, 5% -Tol, C0G, 30ppm/Cel TC, 0.00047uF, Surface Mount, 0603 | C3, C4 | CAP0603 | 470pF | 2 | Mouser | 80-C0603C471JAGAUTO
4.7uF | Capacitor Ceramic 4.7uF 10V X5R 10% 0603 T/R | C5, C8, C10, C11, C12, C13, C14, C20 | CAP0603 | 4.7uF | 8 | Mouser | 187-CL10A475KP8NNWC
100nF | Ceramic Capacitor, Multilayer, Ceramic, 25V, 10% +Tol, 10% -Tol, X7R, 15% TC, 0.1uF, Surface Mount, 0603 | C6, C9, C15, C16, C17, C18, C19, C21, C22, C26, C27, C28, C41, C44 | CAP0603 | 100nF | 14 | Mouser | 187-CL10B104KA8WPNC
1uF | Ceramic Capacitor, Multilayer, Ceramic, 16V, 10% +Tol, 10% -Tol, X7R, 15% TC, 1uF, Surface Mount, 0603 | C7, C23, C24, C34, C38, C39 | CAP0603 | 1uF | 6 | Mouser | 791-SH18B105K160CT
10uF | Ceramic Capacitor, Multilayer, Ceramic, 6.3V, 20% +Tol, 20% -Tol, X5R, 15% TC, 10uF, Surface Mount, 0603 | C25 | CAP0603 | 10uF | 1 | Mouser | 187-CL10A106MQ8NNND
1500uF | Aluminum Electrolytic Capacitor, Polarized, Aluminum (solid Polymer), 6.3V, 20% +Tol, 20% -Tol, 1500uF, Through Hole Mount | C29, C30, C31, C32 | Aluminium Capacitor 10x12.5 | 1500uF | 4 | Mouser | 647-RNU0J152MDN1PH
470uF | Aluminum Electrolytic Capacitor, Aluminum (solid Polymer) | C33 | Aluminium Capacitor 10x12.5 | RR50J471MDN1KX | 1 | Mouser | 647-RR50J471MDN1KX
47nF | Ceramic Capacitor, Multilayer, Ceramic, 16V, 10% +Tol, 10% -Tol, X7R, 15% TC, 0.047uF, Surface Mount, 0603 | C40, C42, C43 | CAP0603 | 47nF | 3 | Mouser | 77-VJ0603Y473KXJCBC
Pins 1x3 | 1x3 2.54mm | CN1 | PIN-1X3 | Pins 1x3 | 1
ESDAULC6-3BP6 | Trans Voltage Suppressor Diode, Bidirectional, 4 Element, Silicon | D1 | SOT-666 | ESDAULC6-3BP6 | 1 | Mouser | 511-ESDAULC63BP6
Value | Single Color LED, Bright Green, Water Clear, 1.1mm | D2, D3, D4, D5, D6, D8, D9 | LED0603 | LED Green | 7 | Mouser | 710-150060VS75000
VS-MBRS130L-M3/5BT | Rectifier Diode, Schottky, 1 Phase, 1 Element, 30V V(RRM), Silicon | D7 | SMB | VS-MBRS130L-M3/5BT | 1 | Mouser | 78-VS-MBRS130L-M35BT
Mounting_Hole_0 | Mounting hole with no connectivity. | H1, H2, H3, H4 | MOUNTING_HOLE_M3 | Mounting_Hole_0 | 4
USB-B | USB Connector, 4 Contact(s), Female, Right Angle, Solder Terminal, Receptacle | J1 | USB-B-FEMALE | USB-B | 1 | Mouser | 490-UJ2-BH-W2-TH
FTSH-105-01-L-DV-K | Board Connector, 10 Contact(s), 2 Row(s), Male, Straight, 0.05 inch Pitch, Surface Mount Terminal, Locking | J2 | CON-2x5-1.27 | Connector_10Pin | 1 | Mouser | 200-FTSH10501LDVKP
691313510002 | Wurth Elektronik, 2 Pin Pluggable Terminal Block, Male | J3, J5, J6 | WR-TBL-5.08/2-M | 691313510002 | 3 | Mouser | 710-691313510002
USB-A | USB Connector | J4 | USB-A-FEMALE | USB-A | 1 | Mouser | 530-SS-52100-001
DC Power Jack | CIRCULAR DC POWER CONNECTOR | J7 | DC Power Jack Right Angled | DC Power Jack | 1 | Mouser | 710-694106301002
Jumper | Interconnection Device | JP1, JP2, JP3, JP4 | PIN-1X2 | Jumper | 4 | Mouser | 855-M7582-46
Inductor | General Purpose Inductor, 10uH, 20%, 1 Element, Ferrite-Core, SMD, 1608M | L1 | IND0603 | 10uH | 1 | Mouser | 810-MLZ1608E100MT
Inductor | Hand made inductance | L2 | COIL_HANDMADE | Inductor | 1
691351500002 | Wurth Elektronik, 2 Pin Pluggable Terminal Block, Female | P1, P2, P3 | WR-TBL-5.08/2-F | 691351500002 | 3 | Mouser | 710-691351500002
ECH8695R-TL-W | Power Field-Effect Transistor, 11A I(D), N-Channel, Metal-oxide Semiconductor FET | Q1 | SOT-28FL | ECH8695R-TL-W | 1 | Mouser | 863-ECH8695R-TL-W
N-MOSFET | Power Field-Effect Transistor, 100A I(D), 25V, 0.00169ohm, 1-Element, N-Channel, Silicon, Metal-oxide Semiconductor FET, MO-235 | Q2, Q3 | SOT-669-5 | PSMN1R2-25YLDX | 2 | Mouser | 771-PSMN1R2-25YLDX
20R | Fixed Resistor, Metal Glaze/thick Film, 0.1W, 20ohm, 75V, 1% +/-Tol, 100ppm/Cel, Surface Mount, 0603 | R1, R2, R19 | RES0603 | 20R | 3 |  | 71-CRCW0603-20-E3
22K1 | 22.1K F 1/16 0603 | R3 | RES0603 | 22K1 | 1 |  | 791-RMC1/16K2212FTP
100R | Fixed Resistor, Metal Glaze/thick Film, 0.1W, 100ohm, 75V, 5% +/-Tol, 100ppm/Cel, Surface Mount, 0603 | R4, R5, R18, R21, R33, R35, R36, R39 | RES0603 | 100R | 8 |  | 603-RC0603JR-13100RL
1K | Fixed Resistor, Metal Glaze/thick Film, 0.1W, 1000ohm, 75V, 1% +/-Tol, 100ppm/Cel, Surface Mount, 0603 | R6, R20, R22 | RES0603 | 1K | 3 |  | 652-CR0603FX-1001ELF
47K5 | Fixed Resistor, Metal Glaze/thick Film, 0.1W, 47500ohm, 75V, 1% +/-Tol, 100ppm/Cel, Surface Mount, 0603 | R7 | RES0603 | 47K5 | 1 |  | 603-RC0603FR-0747K5L
330R | Fixed Resistor, Metal Glaze/thick Film, 0.1W, 330ohm, 75V, 1% +/-Tol, 100ppm/Cel, Surface Mount, 0603 | R8, R9, R24, R27, R28, R29, R46, R47 | RES0603 | 330R | 8 |  | 791-WR06X3300FTL
10K | Fixed Resistor, Metal Glaze/thick Film, 0.1W, 10000ohm, 75V, 1% +/-Tol, 100ppm/Cel, Surface Mount, 0603 | R10, R25, R26, R30, R38, R45 | RES0603 | 10K | 6 |  | 652-CR0603FX-1002ELF
3K3 | Fixed Resistor, Metal Glaze/thick Film, 0.1W, 3300ohm, 75V, 1% +/-Tol, 100ppm/Cel, Surface Mount, 0603 | R11, R40, R41, R42 | RES0603 | 3K3 | 4 | Mouser | 603-RC0603FR-073K3L
4K7 | Fixed Resistor, Metal Glaze/thick Film, 0.1W, 4700ohm, 75V, 1% +/-Tol, 100ppm/Cel, Surface Mount, 0603 | R12, R13, R14, R15, R16, R17, R43, R44 | RES0603 | 4K7 | 8 |  | 603-AC0603FR-134K7L
0R005 | Resistor Current Sense Metal Foil 1206 5m Ohm 1% 1W ±50ppm/°C T/R | R23 | RES1206_KELVIN | 0R005 | 1 |  | 504-MFSA1206R0050FCM
0R010 | Resistor Current Sense Metal Foil 1206 10m Ohm 1% 1W ±50ppm/°C T/R | R31 | RES1206_KELVIN | 0R010 | 1 |  | 504-MFSA1206R0050FCM
5R1 | Fixed Resistor, Thin Film, 0.1W, 5.1ohm, 75V, 0.5% +/-Tol, 25ppm/Cel, Surface Mount, 0603 | R32, R34, R37 | RES0603 | 5R | 3 |  | 603-RT0603DRD075R1L
PTS526 Button | PTS526 Series SPST-NO Off-Mom 160 gf Top Actuated J Lead SMT Tactile Switch | SW1, SW2, SW3 | PTS526 SMG15J SMTR2 LFS | PTS526 Button | 3 | Mouser | 611-TS526SMG15JSMR2L
Test Point | Test Point | TP1, TP2, TP3, TP4, TP5, TP6, TP7, TP8, TP9, TP10, TP11, TP12, TP13, TP14 | TP-1.5HOLE | Test Point | 14
CP2102N-A02-GQFN20R | USB Bus Controller, CMOS | U1 | QFN-20 | CP2102N-A02-GQFN20R | 1 | Mouser | 634-CP2102NA02QFN20R
F280038PMRQ1 | Automotive C2000™ 32-bit MCU 120-MHz 384-KB flash, FPU, TMU with CLA, AES and CAN-FD | U2 | LQFP-64 | F280038CPMRQ1 | 1 | Mouser | 595-F280038PMRQ1
BQ2980 | High-side protector for single-cell Li-ion and Li-polymer batteries with 0-V charge disabled 8-X2QFN -40 to 85 | U3 | X2QFN-8 | BQ2980 | 1 | Mouser | 595-BQ298217RUGR
TPS2116 | Single-Ended Multiplexer, 1 Func, 2 Channel, PDSO8 | U4 | SOTFL50P160X60-8N | TPS2116 | 1 | Mouser | 595-TPS2116DRLR
LP5907QMFX-3.3Q1 | Fixed Positive LDO Regulator, 3.3V, 0.25V Dropout, PDSO5 | U5 | SOT23-5 | LP5907QMFX-3.3Q1 | 1 | Mouser | 595-LP5907QMFX-3.3Q1
DGD05473FN-7 | Half Bridge Based MOSFET Driver | U6 | V-DFN3030-10 | DGD05473FN-7 | 1 | Mouser | 621-DGD05473FN-7
INA181A1 | Operational Amplifier, 1 Func, 500uV Offset-Max, PDSO6 | U7 | SOT23-6 | INA181A1 | 1 | Mouser | 595-INA181A1IDBVR
TLV431 | Three Terminal Voltage Reference, 1 Output, 1.24V, Trim/Adjustable, BIPolar, PDSO5 | U8 | SOT23-5 | TLV431 | 1 | Mouser | 595-TLV431CDBVR

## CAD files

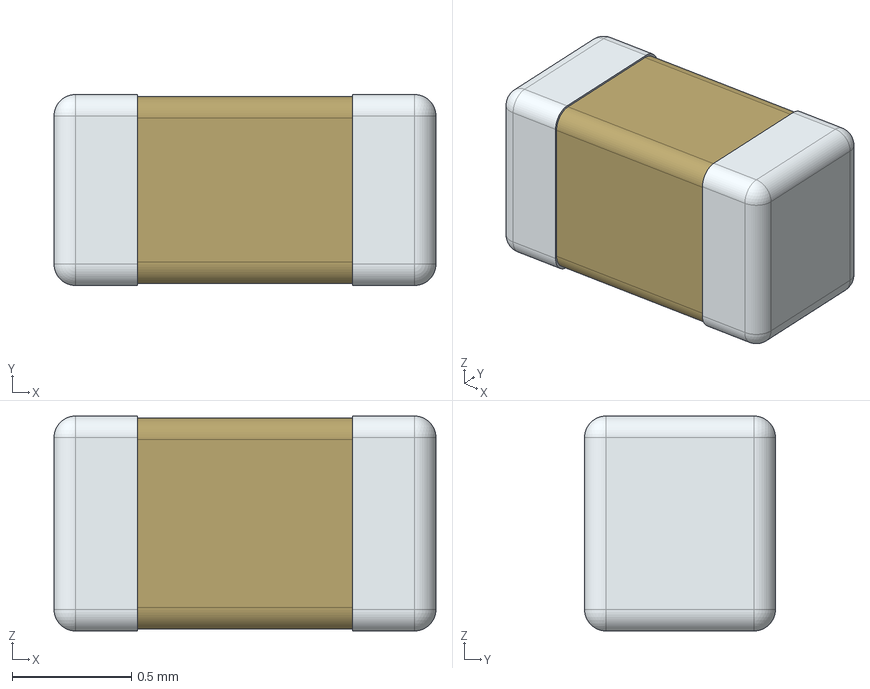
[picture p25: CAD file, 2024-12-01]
Altium/UPS/ALTIUM_EMBEDDED_MODELS/JMK107BJ105MA-T.stp
1.60 x 0.8 x 0.9 mm

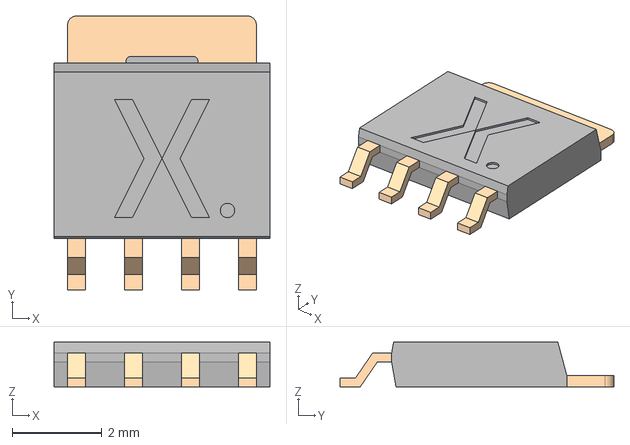
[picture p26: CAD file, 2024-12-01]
Altium/UPS/ALTIUM_EMBEDDED_MODELS/PSMN1R2-25YLDX.stp
4.81 x 6.11 x 0.998 mm

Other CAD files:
CSS/BPSU/CPU1_FLASH/main.obj
CSS/BPSU/CPU1_FLASH/device/device.obj
CSS/BPSU/CPU1_FLASH/device/driverlib/bgcrc.obj
CSS/BPSU/CPU1_FLASH/inc/func.obj
CSS/BPSU/CPU1_FLASH/MUCI/MUCI_MonitorCommands.obj
CSS/BPSU/CPU1_FLASH/MUCI_bsp.obj
CSS/BPSU/CPU1_FLASH/syscfg/c2000ware_libraries.obj
CSS/BPSU/CPU1_FLASH/device/driverlib/asysctl.obj
CSS/BPSU/CPU1_FLASH/inc/pid.obj
CSS/BPSU/CPU1_FLASH/MUCI/MUCI.obj
CSS/BPSU/CPU1_FLASH/syscfg/board.obj
CSS/BPSU/CPU1_FLASH/device/driverlib/i2c.obj
CSS/BPSU/CPU1_FLASH/inc/fsm.obj
CSS/BPSU/CPU1_FLASH/MUCI/MUCI_CRCGenerator.obj
CSS/BPSU/CPU1_FLASH/Term_defs.obj
CSS/BPSU/CPU1_FLASH/device/driverlib/dac.obj
Altium/UPS/ALTIUM_EMBEDDED_MODELS/150060VS75000.stp
Altium/UPS/ALTIUM_EMBEDDED_MODELS/1736036.stp
Altium/UPS/ALTIUM_EMBEDDED_MODELS/694106301002.stp
Altium/UPS/ALTIUM_EMBEDDED_MODELS/CP2102N-A02-GQFN20R.stp
Altium/UPS/ALTIUM_EMBEDDED_MODELS/DGD05473FN-7.stp
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

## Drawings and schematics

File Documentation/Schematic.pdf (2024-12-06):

# Mounting Holes

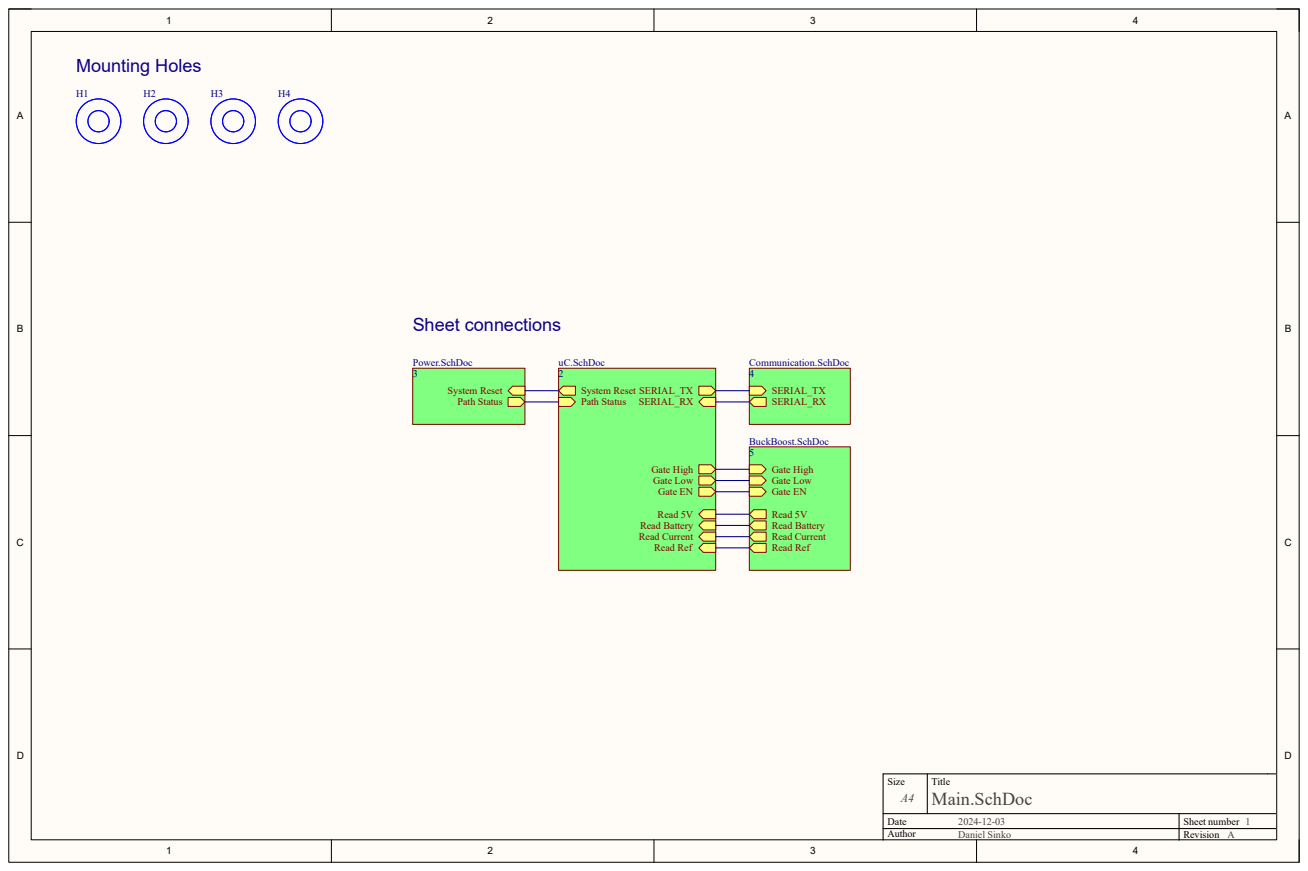
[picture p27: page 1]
Main.SchDoc; Size; Title; Date Author; Daniel Sinko; Revision; Sheet number; SERIAL_TX SERIAL_RX; System Reset; Gate Low Gate EN; Read 5V Read Battery Read Current Read Ref; Gate High; Path Status; uC.SchDoc; Communication.SchDoc; System Reset Path Status; Power.SchDoc; BuckBoost.SchDoc; Sheet connections

# C17 4K⁷ R¹² 100nF C¹⁸

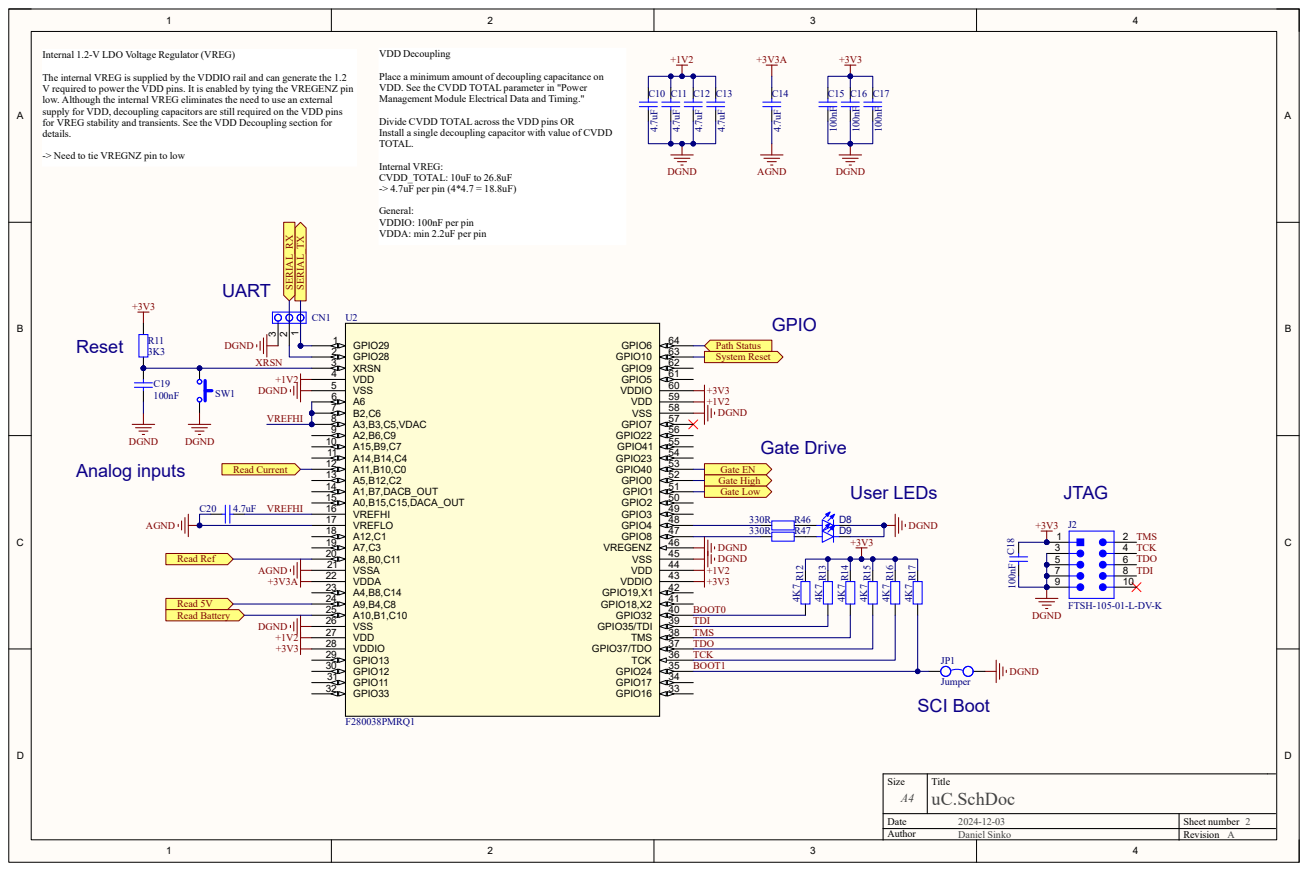
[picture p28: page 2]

Internal 1.2-V LDO Voltage Regulator (VREG)

The internal VREG is supplied by the VDDIO rail and can generate the 1.2
V required to power the VDD pins. It is enabled by tying the VREGENZ pin
low. Although the internal VREG eliminates the need to use an external
supply for VDD, decoupling capacitors are still required on the VDD pins
for VREG stability and transients. See the VDD Decoupling section for
details.

Place a minimum amount of decoupling capacitance on
VDD. See the CVDD TOTAL parameter in "Power
Management Module Electrical Data and Timing."

Divide CVDD TOTAL across the VDD pins OR
Install a single decoupling capacitor with value of CVDD
TOTAL.

-> Need to tie VREGNZ pin to low

General:
VDDIO: 100nF per pin
VDDA: min 2.2uF per pin

## External 2P Battery Pack

Battery | Battery Protection Circuit

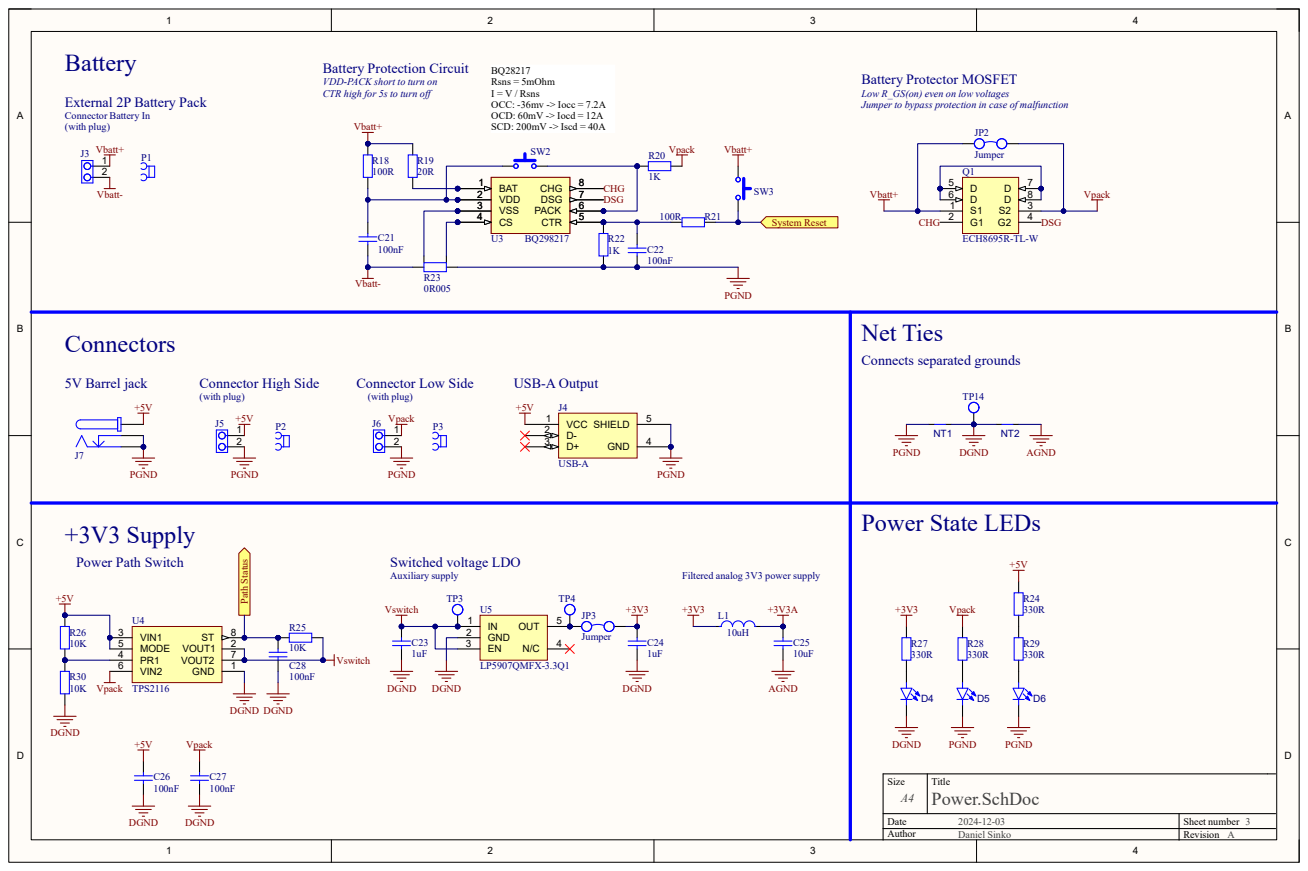
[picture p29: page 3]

Battery Protector MOSFET
Low R_GS(on) even on low voltages
Jumper to bypass protection in case of malfunction

VDD-PACK short to turn on
CTR high for 5s to turn off

Filtered analog 3V3 power supply

# USB to UART

## Self-Powered Connection

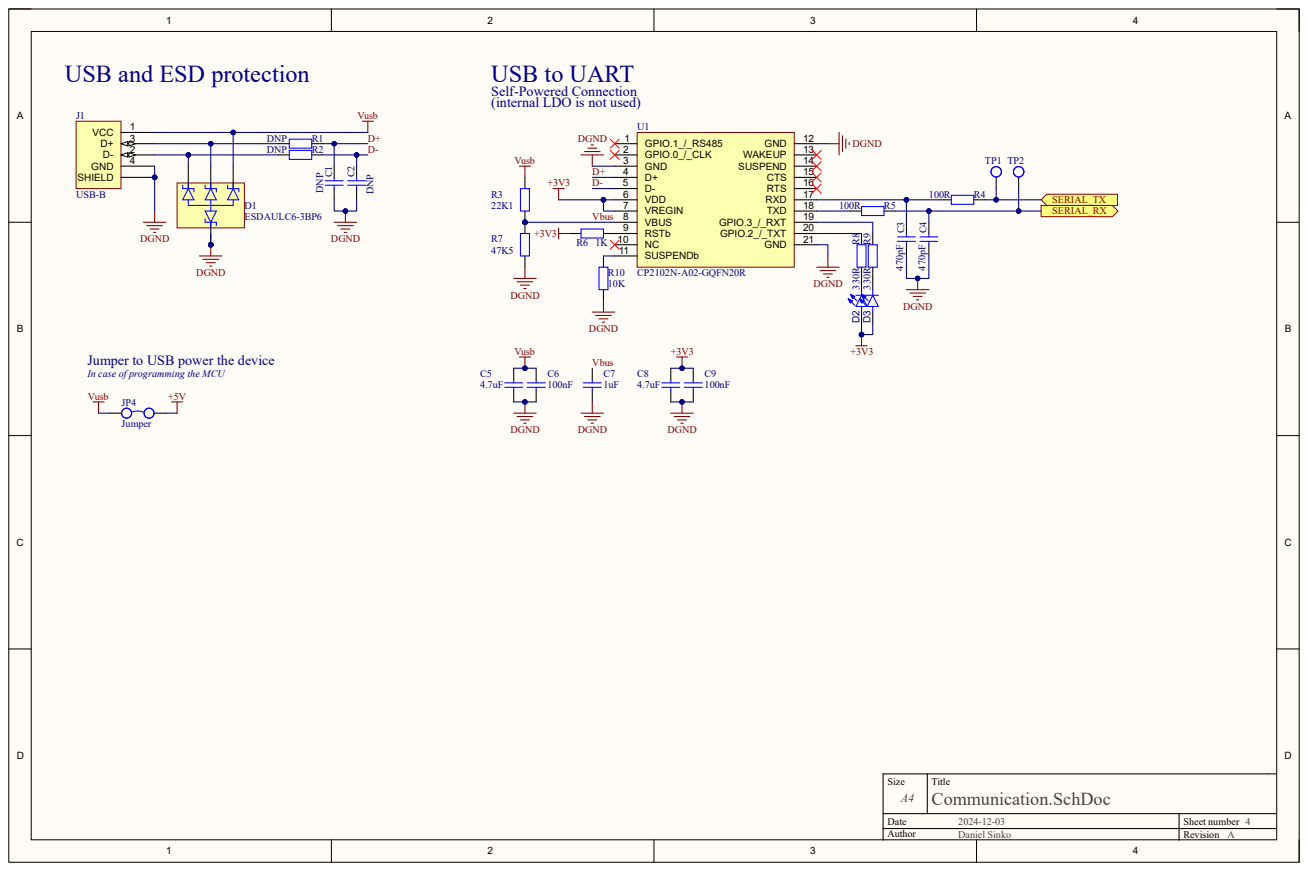
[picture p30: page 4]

USB and ESD protection

Jumper to USB power the device
In case of programming the MCU

# Bidirectional Converter

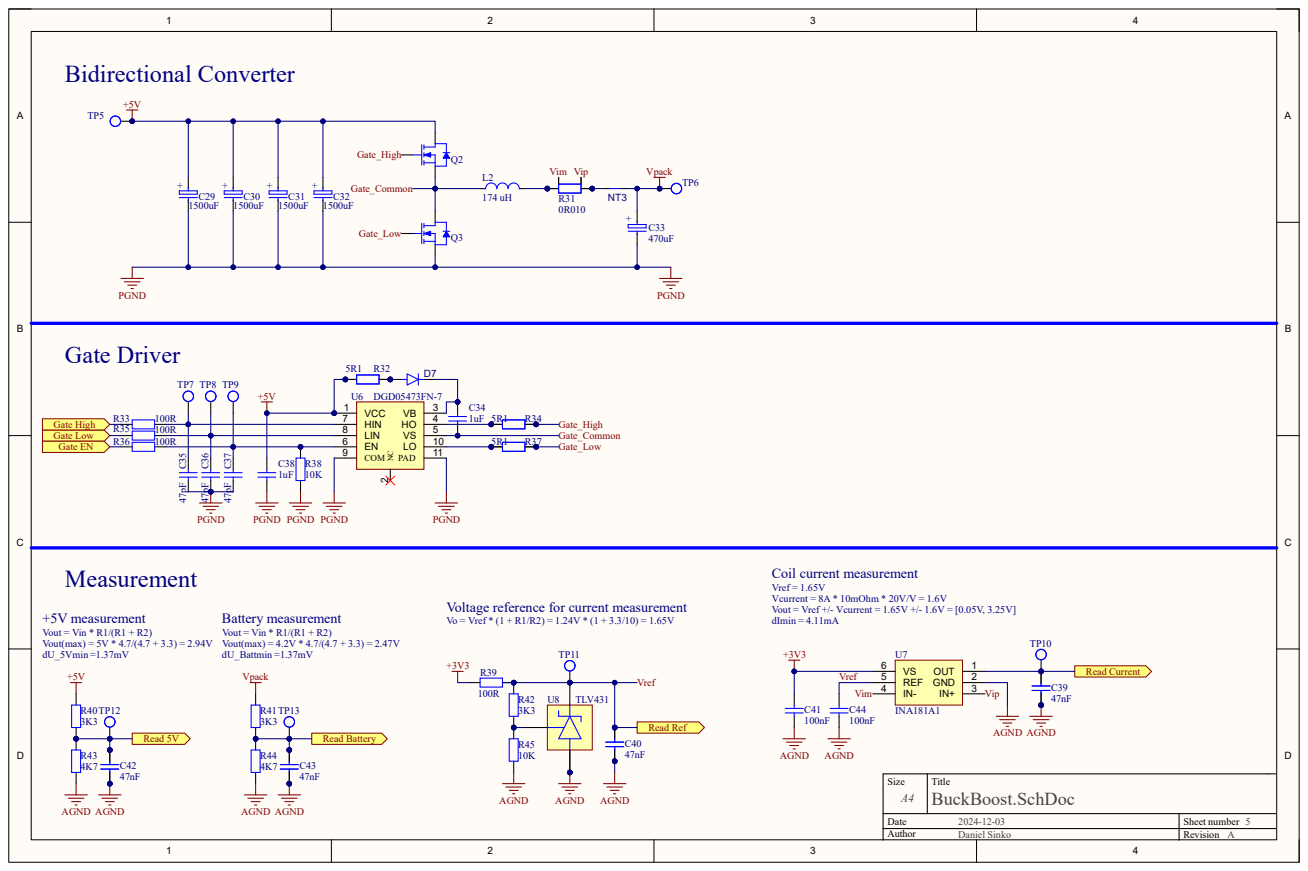
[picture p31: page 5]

Voltage reference for current measurement
Vo = Vref * (1 + R1/R2) = 1.24V * (1 + 3.3/10) = 1.65V

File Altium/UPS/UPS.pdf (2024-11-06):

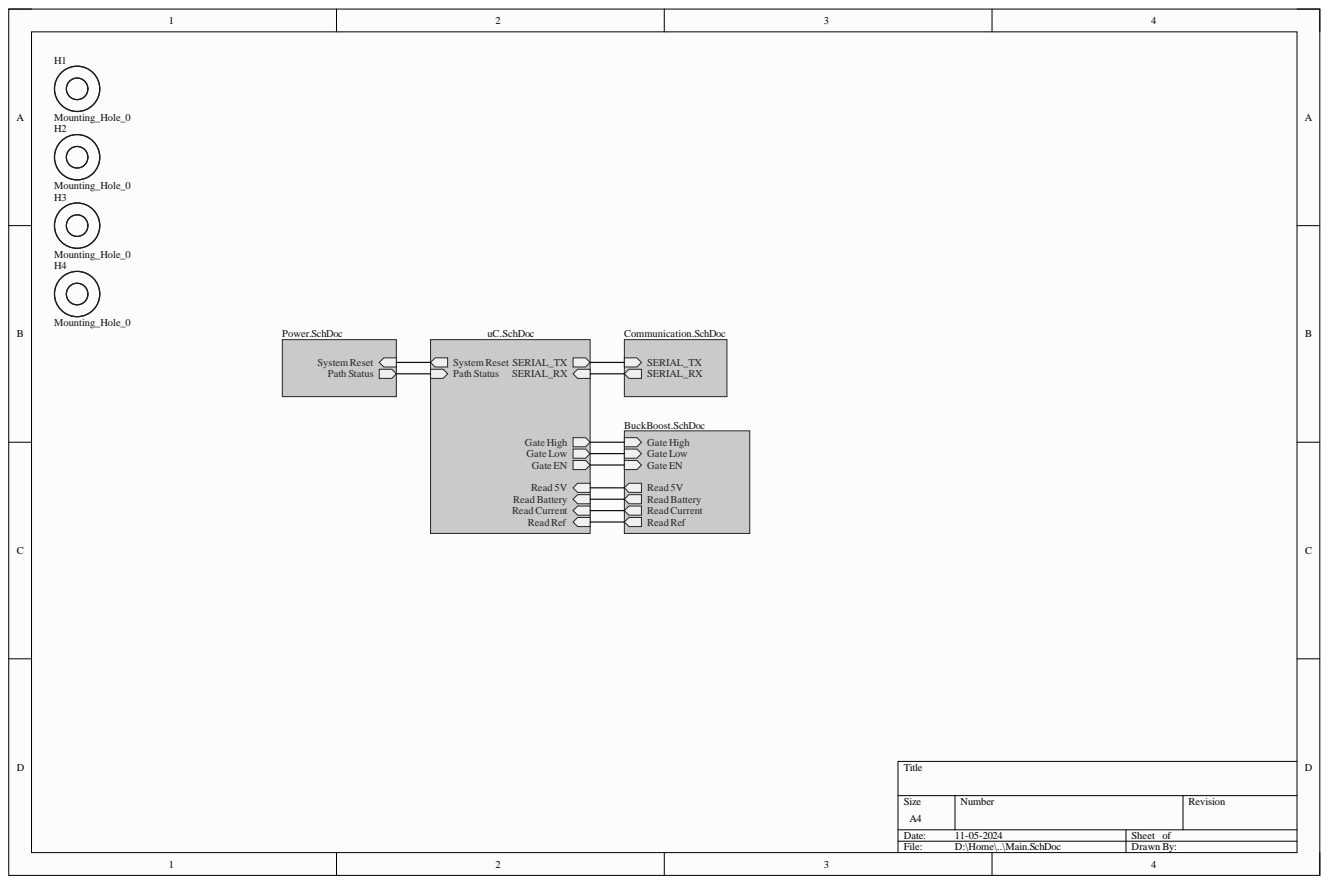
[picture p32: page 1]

Siz e A4 | Numb e r | R evisio n

Da te : 11-05-2 0 24 | She et of
File : D:\Home\. .\Main . S c hD o c | Dr awn B y :

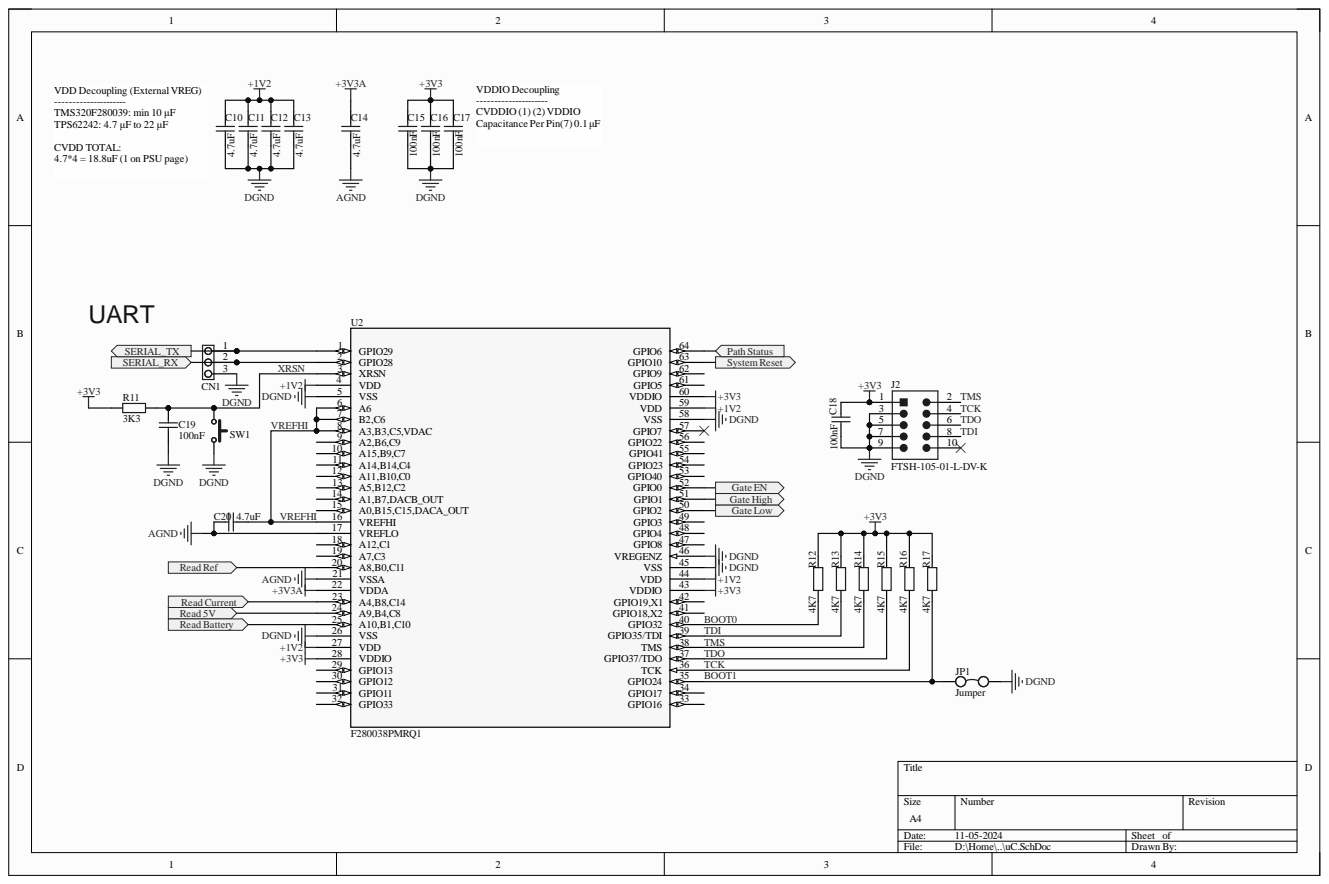
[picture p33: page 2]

VDD Decoupling (External VREG)
TMS320F280039: min 10 μF
TPS62242: 4.7 μF to 22 μF

VDDIO Decoupling
CVDDIO (1)(2) VDDIO
Capacitance Per Pin(7) 0.1 μF

2 | GPIO28 2
3 XRSN | XRSN 3

VDD 4
VSS 5

VREFHI | B2,C6 7

FTSH-105-01-L-DV-K

A9,B4,C8 24 | | BOOT0

VSS 26 | | TDI
VDD 27 | | TMS
VDDIO 28 | | TDO
GPIO13 29 | | TCK
GPIO12 30 | | BOOT1

Size A4 | Number | Revision

Date: 11-05-2024 | Sheet of
File: D:\Home\..\uC.SchDoc | Drawn By:

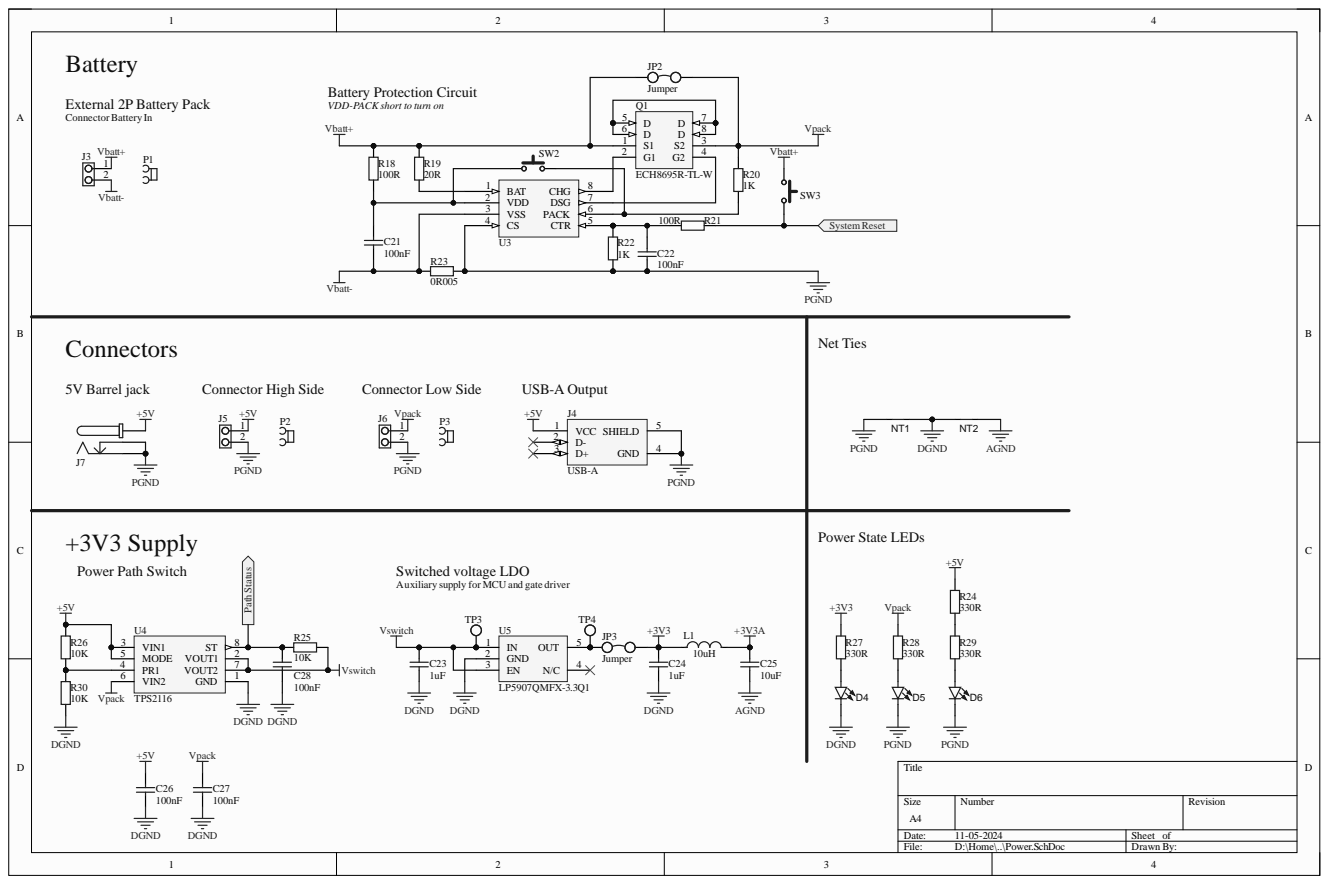
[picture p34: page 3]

VDD-PACK short to turn on

BAT 1

VSS 3

Switched voltage LDO
Auxiliary supply for MCU and gate driver

Size A4 | Number | Revision

Date: 11-05-2024 | Sheet of
File: D:\Home\..\Power.SchDoc | Drawn By:

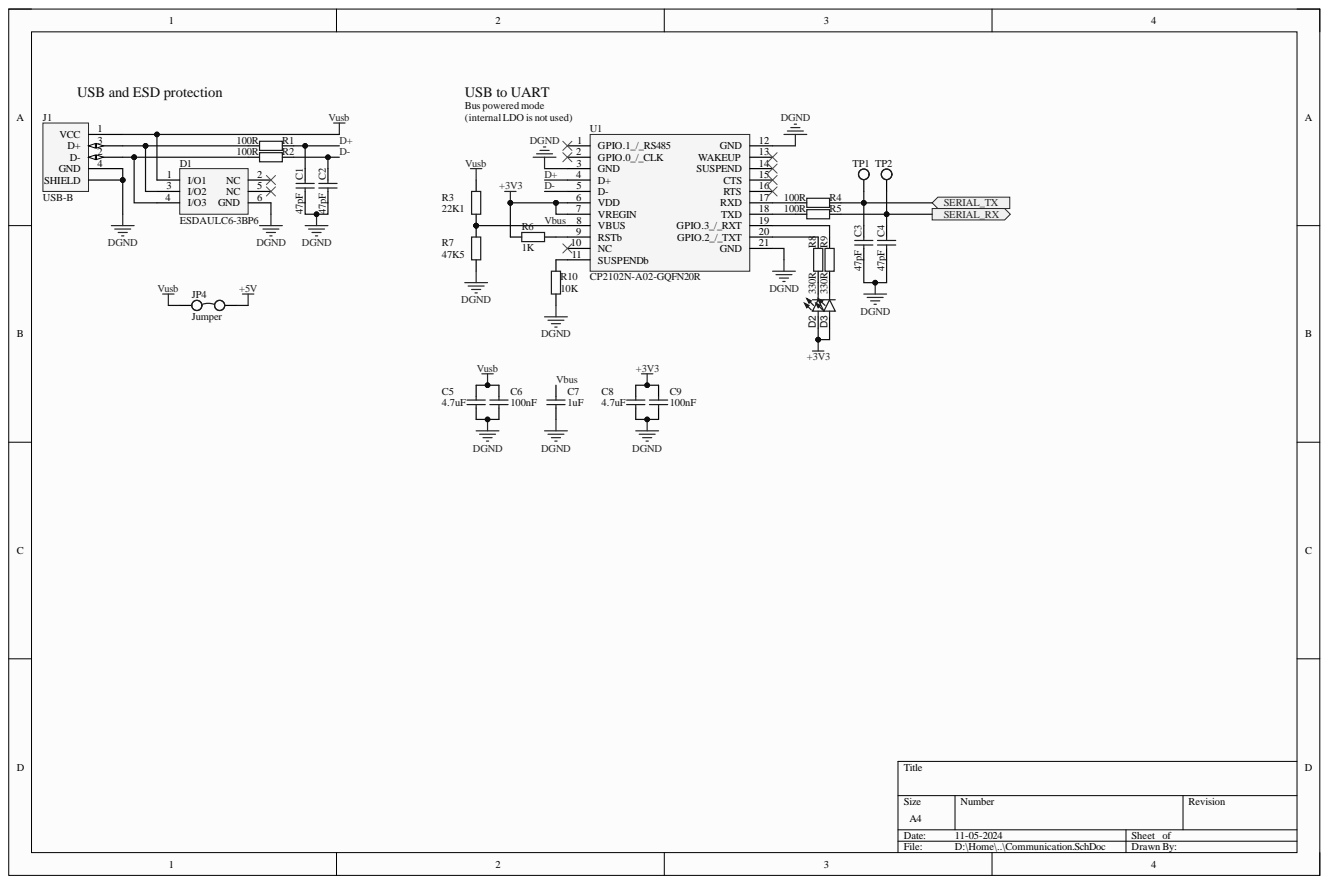
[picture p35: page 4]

USB and ESD protection

rnal LDO is not used)

Siz e A4 | Numb e r | R evisio n

Da te : 11-05-2 0 24 | She et of
File : D:\Home\. .\Communic atio n . S c hD o c | Dr awn B y :

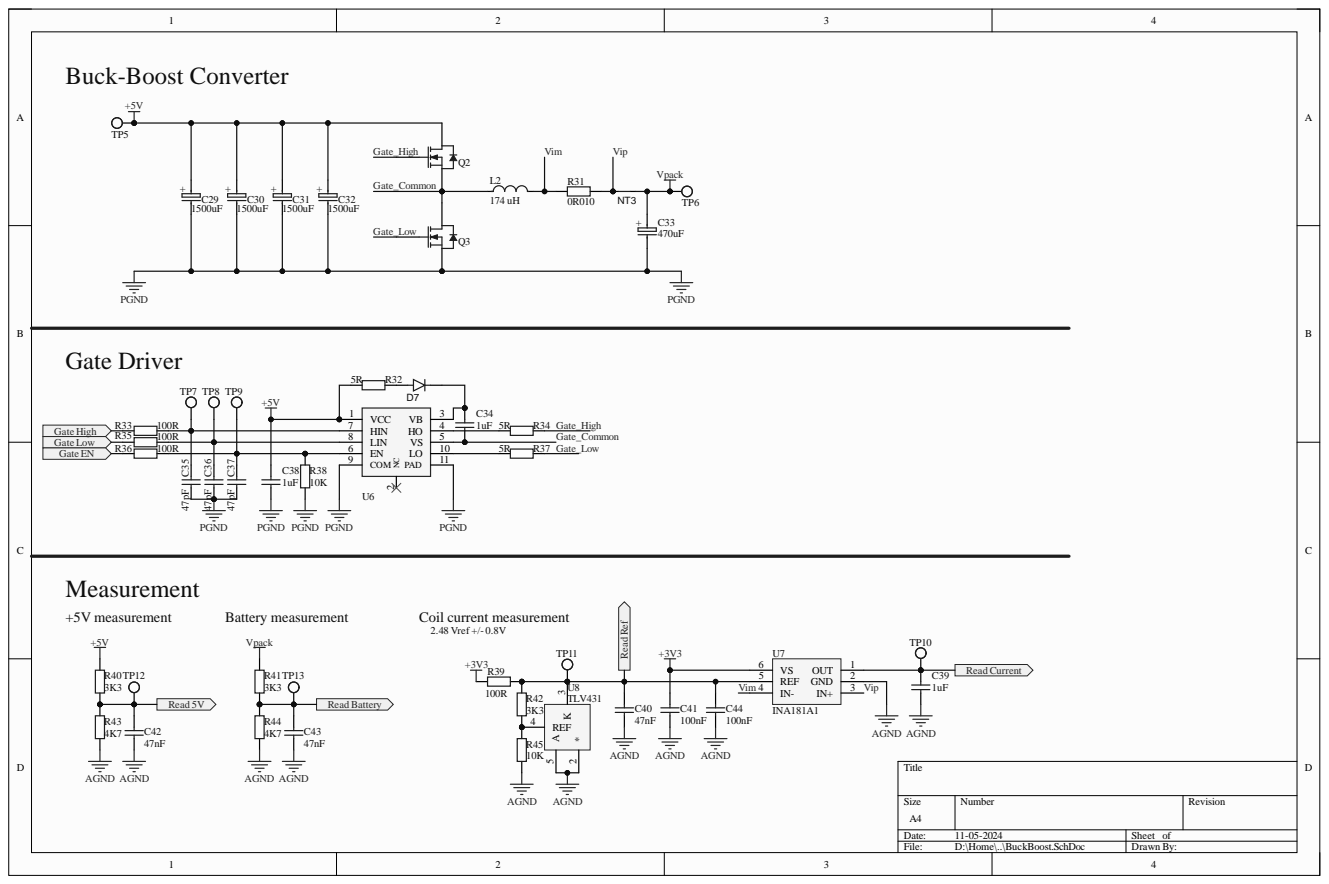
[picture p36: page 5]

LIN 8 HIN 7

Size A4 | Number | Revision

Date: 11-05-2024 | Sheet of
File: D:\Home\..\BuckBoost.SchDoc | Drawn By:

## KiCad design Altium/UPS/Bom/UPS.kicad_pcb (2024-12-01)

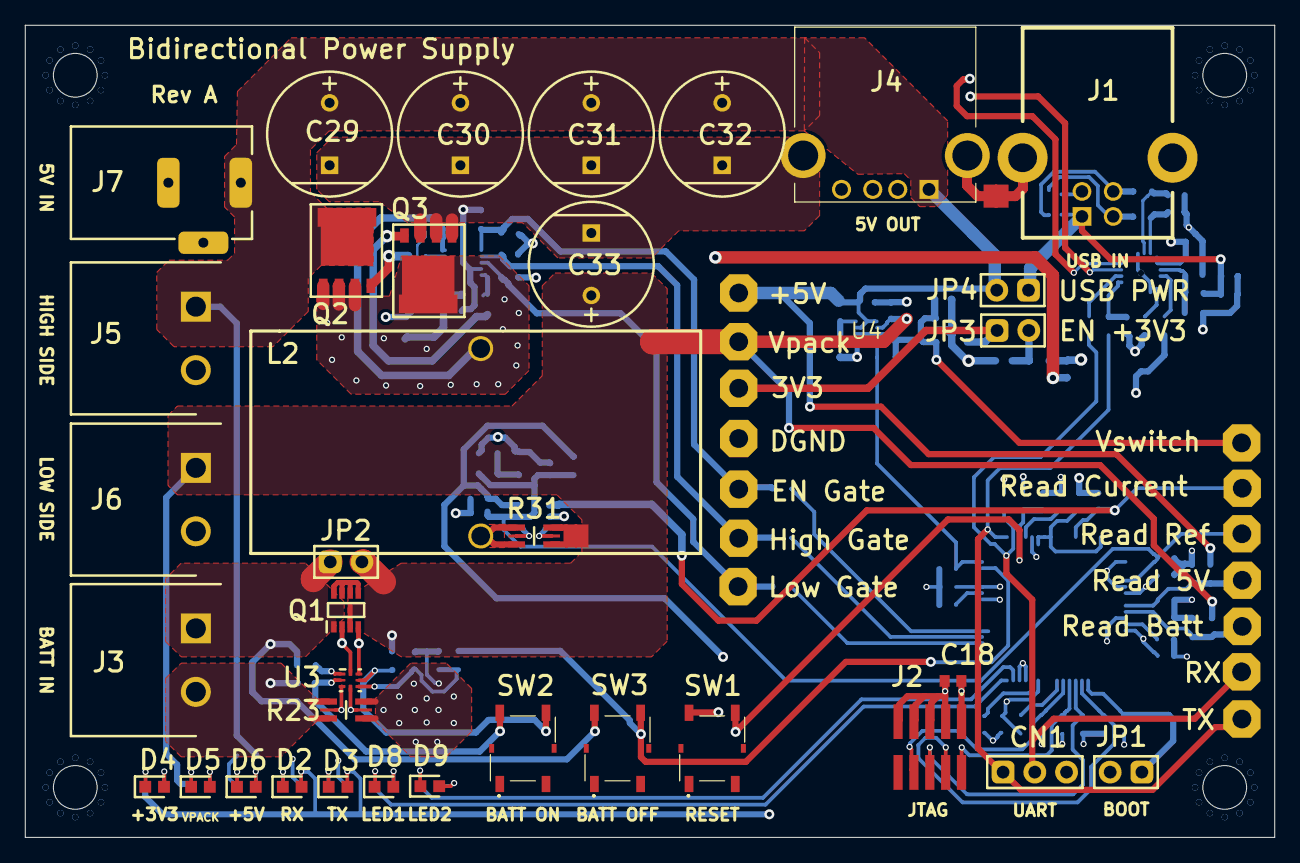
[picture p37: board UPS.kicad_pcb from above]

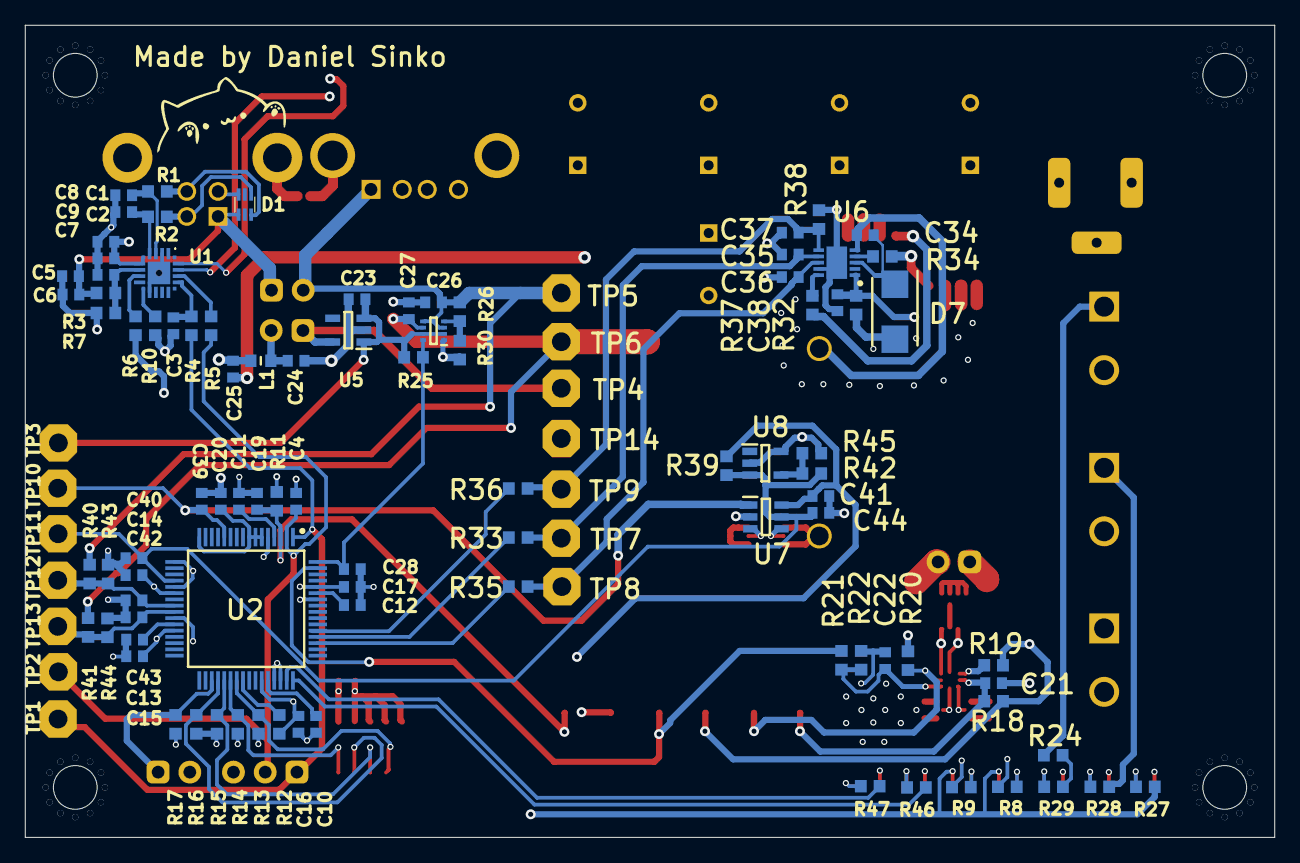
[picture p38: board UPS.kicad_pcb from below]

Board: 4 copper layers, 100.0 x 65.0 mm, 149 parts (108 on the bottom side), 78 nets.

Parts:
C1, C2, C35, C36, C37: 47pF; CAP0603
C3, C4: 470pF; CAP0603
C5, C8, C10, C11, C12, C13, C14, C20: 4.7uF; CAP0603
C6, C9, C15, C16, C17, C18, C19, C21, C22, C26, C27, C28, C41, C44: 100nF; CAP0603
C7, C23, C24, C34, C38, C39: 1uF; CAP0603
C25: 10uF; CAP0603
C29, C30, C31, C32: 1500uF; Aluminium Capacitor 10x12.5
C33: 470uF; Aluminium Capacitor 10x12.5
C40, C42, C43: 47nF; CAP0603
CN1: Pins 1x3; PIN-1X3
D1: ESDAULC6-3BP6; SOT-666
D2, D3, D4, D5, D6, D8, D9: Value; LED0603
D7: VS-MBRS130L-M3/5BT; SMB
H1, H2, H3, H4: Mounting_Hole_0; MOUNTING_HOLE_M3
J1: USB-B; USB-B-FEMALE
J2: FTSH-105-01-L-DV-K; CON-2x5-1.27
J3, J5, J6: 691313510002; WR-TBL-5.08/2-M
J4: USB-A; USB-A-FEMALE
J7: DC Power Jack; DC Power Jack Right Angled
JP1, JP2, JP3, JP4: Jumper; PIN-1X2
L1: Inductor; IND0603
L2: Inductor; COIL_HANDMADE
NT1, NT2, NT3: NetTie_1-1; NETTIE_1.85MM
Q1: ECH8695R-TL-W; SOT-28FL
Q2, Q3: N-MOSFET; SOT-669-5
R1, R2, R19: 20R; RES0603
R3: 22K1; RES0603
R4, R5, R18, R21, R33, R35, R36, R39: 100R; RES0603
R6, R20, R22: 1K; RES0603
R7: 47K5; RES0603
R8, R9, R24, R27, R28, R29, R46, R47: 330R; RES0603
R10, R25, R26, R30, R38, R45: 10K; RES0603
R11, R40, R41, R42: 3K3; RES0603
R12, R13, R14, R15, R16, R17, R43, R44: 4K7; RES0603
R23: 0R005; RES1206_KELVIN
R31: 0R010; RES1206_KELVIN
R32, R34, R37: 5R; RES0603
SW1, SW2, SW3: PTS526 Button; PTS526 SMG15J SMTR2 LFS
TP1, TP2, TP3, TP4, TP5, TP6, TP7, TP8, TP9, TP10, TP11, TP12, TP13, TP14: Test Point; TP-1.5HOLE
U1: CP2102N-A02-GQFN20R; QFN-20
U2: F280038PMRQ1; LQFP-64
U3: BQ2980; X2QFN-8
U4: TPS2116; SOTFL50P160X60-8N
U5: LP5907QMFX-3.3Q1; SOT23-5
U6: DGD05473FN-7; V-DFN3030-10
U7: INA181A1; SOT23-6
U8: TLV431; SOT23-5

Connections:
+1V2: C10.2, C11.2, C12.2, C13.2, U2.4, U2.27, U2.44, U2.59
+3V3: C8.2, C9.1, C15.2, C16.2, C17.2, C18.2, C24.2, C41.1, D2.2, D3.2, J2.1, JP3.2, L1.1, R6.1, R11.2, R12.2, R13.2, R14.2, R15.2, R16.2, R17.2, R27.2, R39.1, U1.6, U1.7, U2.28, U2.43, U2.60, U7.6
+3V3A: C14.2, C25.2, L1.2, U2.22
+5V: C26.2, C29.2, C30.2, C31.2, C32.2, C38.2, J4.1, J5.1, J7.1, JP4.2, Q2.3, R24.2, R26.2, R32.1, R40.2, TP5.1, U4.3, U4.5, U6.1
AGND: C14.1, C20.1, C25.1, C39.1, C40.1, C41.2, C42.1, C43.1, C44.2, NT2.2, R43.1, R44.1, R45.1, U2.17, U2.21, U7.2, U8.2, U8.5
BOOT0: R12.1, U2.40
BOOT1: JP1.1, R17.1, U2.35
D+: C1.2, R1.1, U1.4
D-: C2.2, R2.1, U1.5
DGND: C1.1, C2.1, C3.1, C4.1, C5.1, C6.2, C7.1, C8.1, C9.2, C10.1, C11.1, C12.1, C13.1, C15.1, C16.1, C17.1, C18.1, C19.2, C23.1, C24.1, C26.1, C27.1, C28.1, CN1.3, D1.6, D4.1, D8.1, D9.1, J1.0, J1.4, J2.3, J2.5, J2.7, J2.9, JP1.2, NT1.2, NT2.1, R7.1, R10.1, R30.1, SW1.1, TP14.1, U1.3, U1.12, U1.21, U2.5, U2.26, U2.45, U2.46, U2.58, U4.1, U5.2
Gate EN: R36.1, U2.53
Gate High: R33.1, U2.52
Gate Low: R35.1, U2.51
Gate_Common: C34.1, L2.1, Q2.2, Q3.3, U6.5
Gate_High: Q2.1, R34.2
Gate_Low: Q3.1, R37.2
NetC3_2: C3.2, R4.1, U1.17
NetC21_2: C21.2, R18.1, SW2.1, U3.2
NetC22_2: C22.2, R21.1, R22.2, U3.5
NetC34_2: C34.2, D7.1, U6.3
NetC35_2: C35.2, R33.2, TP7.1, U6.7
NetC36_2: C36.2, R35.2, TP8.1, U6.8
NetC37_2: C37.2, R36.2, R38.1, TP9.1, U6.6
NetD1_3: D1.3, J1.3, R1.2
NetD1_4: D1.4, J1.2, R2.2
NetD2_1: D2.1, R8.2
NetD3_1: D3.1, R9.2
NetD4_2: D4.2, R27.1
NetD5_2: D5.2, R28.1
NetD6_2: D6.2, R29.1
NetD7_2: D7.2, R32.2
NetD8_2: D8.2, R46.1
NetD9_2: D9.2, R47.1
NetJP3_1: JP3.1, TP4.1, U5.5
NetL2_2: L2.2, R31.1
NetNT3_1: NT3.1, R31.2
NetQ1_2: Q1.2, U3.8
NetQ1_4: Q1.4, U3.7
NetQ1_5: Q1.5, Q1.6, Q1.7, Q1.8
NetR5_1: R5.1, U1.18
NetR6_2: R6.2, U1.9
NetR8_1: R8.1, U1.20
NetR9_1: R9.1, U1.19
NetR10_2: R10.2, U1.11
NetR19_1: R19.1, U3.1
NetR20_1: R20.1, SW2.2, U3.6
NetR23_3: R23.3, U3.3
NetR23_4: R23.4, U3.4
NetR24_1: R24.1, R29.2
NetR26_1: R26.1, R30.2, U4.4
NetR34_1: R34.1, U6.4
NetR37_1: R37.1, U6.10
NetR42_1: R42.1, R45.2, U8.4
NetR46_2: R46.2, U2.48
NetR47_2: R47.2, U2.47
PGND: C22.1, C29.1, C30.1, C31.1, C32.1, C33.1, C35.1, C36.1, C37.1, C38.1, D5.1, D6.1, J4.4, J4.5, J5.2, J6.2, J7.2, J7.3, NT1.1, Q3.2, R22.1, R23.2, R38.2, U6.9, U6.11
Path Status: C28.2, R25.2, U2.64, U4.8
Read 5V: C42.2, R40.1, R43.2, TP12.1, U2.24
Read Battery: C43.2, R41.1, R44.2, TP13.1, U2.25
Read Current: C39.2, TP10.1, U2.12, U7.1
Read Ref: C40.2, C44.1, R39.2, R42.2, TP11.1, U2.20, U7.5, U8.3
SERIAL_RX: C4.2, CN1.2, R5.2, TP2.1, U2.2
SERIAL_TX: CN1.1, R4.2, TP1.1, U2.1
System Reset: R21.2, SW3.2, U2.63
TCK: J2.4, R16.1, U2.36
TDI: J2.8, R13.1, U2.39
TDO: J2.6, R15.1, U2.37
TMS: J2.2, R14.1, U2.38
VREFHI: C20.2, U2.6, U2.7, U2.8, U2.16
Vbatt+: J3.1, JP2.1, Q1.1, R18.2, R19.2, SW3.1
Vbatt-: C21.1, J3.2, R23.1
Vbus: C7.2, R3.1, R7.2, U1.8
Vim: R31.3, U7.4
Vip: R31.4, U7.3
Vpack: C27.2, C33.2, J6.1, JP2.2, NT3.2, Q1.3, R20.2, R28.2, R41.2, TP6.1, U4.6
Vswitch: C23.2, R25.1, TP3.1, U4.2, U4.7, U5.1, U5.3
Vusb: C5.2, C6.1, D1.1, J1.1, JP4.1, R3.2
XRSN: C19.1, R11.1, SW1.2, U2.3

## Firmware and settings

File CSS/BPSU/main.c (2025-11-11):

//#############################################################################
//
// FILE:   main.c
//
//! This project is the firmware for the Bidirectional Power Supply.
//! The peripherials (ePWM, ADC, GPIO, TIMER, SCI)
//! are configured with sysconfig.
//! The main function controls the duty cycle of the pwm.
//
// Created on: 2024.11.17.
// Author: Daniel Sinko
//
//#############################################################################

//
// Included Files
//
#include <stdio.h>
#include <stdbool.h>
#include "driverlib.h"
#include "device.h"
#include "board.h"
#include "func.h"
#include "c2000ware_libraries.h"

typedef unsigned int Uint16;
#include "f28003x_piectrl.h"

#include "MUCI_bsp.h"

#include "pid.h"
#include "globals.h"
#include "fsm.h"

//
// Globals
//

// Flags
bool timer100uSecFlag = 0;
bool timer1mSecFlag = 0;
bool timer5SecFlag = 0;
bool adcFlag = 0;
bool tzFlag = 0;

// Counters
uint32_t BackgndCounter = 0;
uint32_t timer1Cnt = 0;
uint32_t timer5Cnt = 0;
uint32_t tzIntCnt = 0;
uint32_t adcIntCnt= 0;
uint32_t ledCnt = 0;
uint32_t ellapsedTime = 0;
uint32_t lastTime = 0;

// Adc values
typedef struct {
    uint16_t Main;
    uint16_t Batt;
    uint16_t Current;
    uint16_t Ref;
} adcStruct_t;
adcStruct_t adc;

float VMain;
float VMainAvg;
float VMainBuff[16];
uint8_t VMainBuffCnt;
float VBatt;
float VCurr;
float VRef;
float VLimit = 4.85;
float IBatt;
float PWMVal = 0.7;

// Control variables
uint32_t StateTestMode = 0;
#define HANDLE_TEST_MODE 0
uint32_t HandleTestMode = 0; // Currently not in use
uint32_t ackTripZone = 0;
uint16_t ControlEnabled = 0;
uint8_t MuciEnable = 0;

State_t gateState = {.state = 0, .enable = 0, .disable = 0};
State_t pwmState = {.state = 0, .enable = 0, .disable = 0};

typedef struct {
    bool buck;
    bool boost;
    bool current;
    bool pwm;
    bool buckPwm;
} enable_t;
enable_t enReg;

typedef struct {
    uint32_t t[10];
} timer_t;
volatile timer_t timer;
#define TIMER 1
#define TIMER_PRD 10000
#define TIMER_READ_CYCLES 7
uint8_t timerCnt = 0;

void inline SampleTime() {
#if TIMER
    timer.t[timerCnt] = TIMER_PRD - CPUTimer_getTimerCount(TIMER_0_BASE) - timerCnt*TIMER_READ_CYCLES;
    timerCnt = timerCnt + 1;
#endif
}

void inline SampleTimeReset() {
#if TIMER
    CPUTimer_reloadTimerCounter(TIMER_0_BASE);
    // Wait two cycle to take effect
    asm("       NOP");
    asm("       NOP");
    timerCnt = 0;
#endif
}



//
// Interrupt Function Prototypes
//
__interrupt void INT_TIMER_1MS_ISR(void);
__interrupt void INT_ADC0_1_ISR(void);

//
// Function Prototypes
//
void Application();
void Control();

//
// Main
//
void main(void)
{
    // Initialize device clock and peripherals
    Device_init();

    // Disable pin locks and enable internal pull-ups.
    Device_initGPIO();

    // Initialize PIE and clear PIE registers. Disables CPU interrupts.
    Interrupt_initModule();

    // Initialize the PIE vector table with pointers to the shell Interrupt
    // Service Routines (ISR).
    Interrupt_initVectorTable();

    // PinMux and Peripheral Initialization
    Board_init();

    // Disable ePWM1 by default
    //SysCtl_disablePeripheral(SYSCTL_PERIPH_CLK_EPWM1);

    // Initialize MUCI variable monitoring
    MUCI_bsp_Init();

    // Disable PWM output, enable gate,
    GateControl(0);
    GPIO_writePin(GATE_EN, 1);
    gateState.state = 1;

    // Enable Global Interrupt (INTM) and real time interrupt (DBGM)
    EINT;
    ERTM;

    while(1) {
        BackgndCounter++;
        MUCI_bsp_Background();

        Control();

        if(timer100uSecFlag) {
            timer100uSecFlag = 0;

            if(!MuciEnable) {
                MUCI_Recorder_Trigger();
            }
        }

        if(timer1mSecFlag) {
            timer1mSecFlag = 0;

            // Update states manually if { StateTestMode = 1 }
            if(!StateTestMode) {
                UpdatePowerState();
            }
            Application();
        }
    }
}

//
// Interrupt Functions
//

// 1ms timer interrupt for timing
// Extra 8 cycles to enable nesting vs ISR routine + return ...
#pragma CODE_SECTION(INT_TIMER_1MS_ISR, ".TI.ramfunc")
__interrupt void INT_TIMER_1_ISR(void) {
    // === Enables IT priority for ADC_IT ===
    // Save PIEIER register for later
    uint16_t TempPIEIER;
    TempPIEIER = PieCtrlRegs.PIEIER1.all;

    // Enable Group 1 interrupts
    IER |= 0x0001;
    IER &= 0x0001;

    // Set group priority to allow INT1.1 to interrupt current ISR
    PieCtrlRegs.PIEIER1.all &= 0x0001;
    PieCtrlRegs.PIEACK.all = 0xFFFF; // Enable PIE interrupts

    // Clear INTM to enable interrupts
    asm("       NOP"); // Wait one cycle
    EINT;
    // === === === === ===

    // ISR code...
    timer100uSecFlag = 1;

    static PowerState lastState = BOOT;

    if(lastState != powerState) {
        lastState = powerState;
        timer5SecFlag = 0;
        timer5Cnt = 0;
    }

    timer5Cnt++;
    if(timer5Cnt >= 50000) {
        timer5SecFlag = 1;
        timer5Cnt = 0;
    }

    timer1Cnt++;
    if(timer1Cnt >= 10) {
        timer1mSecFlag = 1;
        timer1Cnt = 0;
    }

    // Restore state
    DINT;
    PieCtrlRegs.PIEIER1.all = TempPIEIER;

    // The CPU acknowledges the interrupt.
}

// ADC end of conversion interrupt
// ADC conversion is generated at every ePWM ZRO/PRD events
#pragma CODE_SECTION(INT_ADC0_1_ISR, ".TI.ramfunc")
__interrupt void INT_ADC0_1_ISR(void) {
    SampleTimeReset();
    SampleTime();

    adcFlag = 1;
    adcIntCnt++;

    // Read ADC
    adc.Current = ADC_readResult(ADCARESULT_BASE, ADC_SOC_NUMBER0);
    adc.Main = ADC_readResult(ADCARESULT_BASE, ADC_SOC_NUMBER1);
    adc.Ref = ADC_readResult(ADCBRESULT_BASE, ADC_SOC_NUMBER0);
    adc.Batt = ADC_readResult(ADCBRESULT_BASE, ADC_SOC_NUMBER1);

    SampleTime();

    // Calculate voltages
    // Other 2 value calculated at the main Application every 1ms
    VMain = (float)adc.Main * 0.001371343; // Adc.Main/4096 * 3.3 * (4.7+3.3)/4.7
    VBatt = (float)adc.Batt * 0.001371343; // Adc.Batt/4096 * 3.3 * (4.7+3.3)/4.7
    VCurr = (float)adc.Current * 0.000805664; // Adc.Current/4096*3.3
    IBatt = -(VCurr-VRef) * 5; // -(VCurr-VRef) / 0.2f;

    SampleTime();

    // Manual/Automatic conversion control
#if HANDLE_TEST_MODE
    if(enReg.buck)          ControlBuck(VBuckReg.ref);
    else if(enReg.boost)    ControlBoost(VBoostReg.ref);
    else if(enReg.current)  ControlCurrent(IBattReg.ref);
    else if(enReg.pwm)      EPWM_setCounterCompareValue(GATE_PWM_BASE, EPWM_COUNTER_COMPARE_A, (1.0-PWMVal) * TBPRD);
#else
    HandlePowerStates();
#endif

    SampleTime();

    // Display values in graph
    if(MuciEnable) {
        MUCI_Recorder_Trigger();
    }

    SampleTime();

    // Check if overflow has occurred (continuous mode)
    if(true == ADC_getInterruptOverflowStatus(ADCA_BASE, ADC_INT_NUMBER1)) {
        ADC_clearInterruptOverflowStatus(ADCA_BASE, ADC_INT_NUMBER1);
        ADC_clearInterruptStatus(ADCA_BASE, ADC_INT_NUMBER1);
    }

    // Clear the interrupt flag
    ADC_clearInterruptStatus(ADCA_BASE, ADC_INT_NUMBER1);

    // Acknowledge the interrupt
    Interrupt_clearACKGroup(INTERRUPT_ACK_GROUP1);

    SampleTime();
}

//
// Functions
//

// Function to toggle peripherals
void Control() {
    if(pwmState.enable) {
        pwmState.enable = 0;
        GateControl(1);
        //SysCtl_enablePeripheral(SYSCTL_PERIPH_CLK_EPWM1);
    }

    if(pwmState.disable) {
        pwmState.disable = 0;
        GateControl(0);
        SysCtl_disablePeripheral(SYSCTL_PERIPH_CLK_EPWM1);
    }

    if(gateState.enable) {
        gateState.state = 1;
        gateState.enable = 0;
        GPIO_writePin(GATE_EN, 1);
    }

    if(gateState.disable) {
        gateState.state = 0;
        gateState.disable = 0;
        GPIO_writePin(GATE_EN, 0);
    }
}

// Main calculations
void Application() {
    VRef = (float)adc.Ref * 0.000805664; // Adc.Ref/4096 * 3.3

    VMainBuff[VMainBuffCnt] = VMain;
    VMainBuffCnt++;
    if(VMainBuffCnt >= 16) {
        VMainBuffCnt = 0;
    }
    VMainAvg = 0;
    int i;
    for(i = 0; i < 16; i++) {
        VMainAvg += VMainBuff[i];
    }
    VMainAvg /= 16;

    LedState();
}

//
// End of File
//

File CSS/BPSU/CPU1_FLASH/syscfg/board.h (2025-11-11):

/*
 * Copyright (c) 2020 Texas Instruments Incorporated - http://www.ti.com
 * All rights reserved.
 *
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
 * *  Redistributions of source code must retain the above copyright
 *    notice, this list of conditions and the following disclaimer.
 *
 * *  Redistributions in binary form must reproduce the above copyright
 *    notice, this list of conditions and the following disclaimer in the
 *    documentation and/or other materials provided with the distribution.
 *
 * *  Neither the name of Texas Instruments Incorporated nor the names of
 *    its contributors may be used to endorse or promote products derived
 *    from this software without specific prior written permission.
 *
 * THIS SOFTWARE IS PROVIDED BY THE COPYRIGHT HOLDERS AND CONTRIBUTORS "AS IS"
 * AND ANY EXPRESS OR IMPLIED WARRANTIES, INCLUDING, BUT NOT LIMITED TO,
 * THE IMPLIED WARRANTIES OF MERCHANTABILITY AND FITNESS FOR A PARTICULAR
 * PURPOSE ARE DISCLAIMED. IN NO EVENT SHALL THE COPYRIGHT OWNER OR
 * CONTRIBUTORS BE LIABLE FOR ANY DIRECT, INDIRECT, INCIDENTAL, SPECIAL,
 * EXEMPLARY, OR CONSEQUENTIAL DAMAGES (INCLUDING, BUT NOT LIMITED TO,
 * PROCUREMENT OF SUBSTITUTE GOODS OR SERVICES; LOSS OF USE, DATA, OR PROFITS;
 * OR BUSINESS INTERRUPTION) HOWEVER CAUSED AND ON ANY THEORY OF LIABILITY,
 * WHETHER IN CONTRACT, STRICT LIABILITY, OR TORT (INCLUDING NEGLIGENCE OR
 * OTHERWISE) ARISING IN ANY WAY OUT OF THE USE OF THIS SOFTWARE,
 * EVEN IF ADVISED OF THE POSSIBILITY OF SUCH DAMAGE.
 *
 */

#ifndef BOARD_H
#define BOARD_H

//*****************************************************************************
//
// If building with a C++ compiler, make all of the definitions in this header
// have a C binding.
//
//*****************************************************************************
#ifdef __cplusplus
extern "C"
{
#endif

//
// Included Files
//

#include "driverlib.h"
#include "device.h"

//*****************************************************************************
//
// PinMux Configurations
//
//*****************************************************************************

//
// ANALOG -> myANALOGPinMux0 Pinmux
//

//
// EPWM1 -> GATE_PWM Pinmux
//
//
// EPWM1_A - GPIO Settings
//
#define GPIO_PIN_EPWM1_A 0
#define GATE_PWM_EPWMA_GPIO 0
#define GATE_PWM_EPWMA_PIN_CONFIG GPIO_0_EPWM1_A
//
// EPWM1_B - GPIO Settings
//
#define GPIO_PIN_EPWM1_B 1
#define GATE_PWM_EPWMB_GPIO 1
#define GATE_PWM_EPWMB_PIN_CONFIG GPIO_1_EPWM1_B
//
// GPIO40 - GPIO Settings
//
#define GATE_EN_GPIO_PIN_CONFIG GPIO_40_GPIO40
//
// GPIO6 - GPIO Settings
//
#define PATH_STATUS_GPIO_PIN_CONFIG GPIO_6_GPIO6
//
// GPIO10 - GPIO Settings
//
#define SYSTEM_RESET_GPIO_PIN_CONFIG GPIO_10_GPIO10
//
// GPIO4 - GPIO Settings
//
#define LED1_GPIO_PIN_CONFIG GPIO_4_GPIO4
//
// GPIO8 - GPIO Settings
//
#define LED2_GPIO_PIN_CONFIG GPIO_8_GPIO8

//*****************************************************************************
//
// ADC Configurations
//
//*****************************************************************************
#define ADC0_BASE ADCA_BASE
#define ADC0_RESULT_BASE ADCARESULT_BASE
#define ADC0_SOC0 ADC_SOC_NUMBER0
#define ADC0_FORCE_SOC0 ADC_FORCE_SOC0
#define ADC0_SAMPLE_WINDOW_SOC0 75
#define ADC0_TRIGGER_SOURCE_SOC0 ADC_TRIGGER_EPWM1_SOCA
#define ADC0_CHANNEL_SOC0 ADC_CH_ADCIN11
#define ADC0_SOC1 ADC_SOC_NUMBER1
#define ADC0_FORCE_SOC1 ADC_FORCE_SOC1
#define ADC0_SAMPLE_WINDOW_SOC1 75
#define ADC0_TRIGGER_SOURCE_SOC1 ADC_TRIGGER_EPWM1_SOCA
#define ADC0_CHANNEL_SOC1 ADC_CH_ADCIN9
void ADC0_init();

#define ADC1_BASE ADCB_BASE
#define ADC1_RESULT_BASE ADCBRESULT_BASE
#define ADC1_SOC0 ADC_SOC_NUMBER0
#define ADC1_FORCE_SOC0 ADC_FORCE_SOC0
#define ADC1_SAMPLE_WINDOW_SOC0 75
#define ADC1_TRIGGER_SOURCE_SOC0 ADC_TRIGGER_EPWM1_SOCA
#define ADC1_CHANNEL_SOC0 ADC_CH_ADCIN0
#define ADC1_SOC1 ADC_SOC_NUMBER1
#define ADC1_FORCE_SOC1 ADC_FORCE_SOC1
#define ADC1_SAMPLE_WINDOW_SOC1 75
#define ADC1_TRIGGER_SOURCE_SOC1 ADC_TRIGGER_EPWM1_SOCA
#define ADC1_CHANNEL_SOC1 ADC_CH_ADCIN1
void ADC1_init();


//*****************************************************************************
//
// ASYSCTL Configurations
//
//*****************************************************************************

//*****************************************************************************
//
// CMPSS Configurations
//
//*****************************************************************************
#define COMP_CURRENT_BASE CMPSS1_BASE
#define COMP_CURRENT_HIGH_BASE CMPSS1_BASE    
#define COMP_CURRENT_LOW_BASE CMPSS1_BASE    
void COMP_CURRENT_init();

//*****************************************************************************
//
// CPUTIMER Configurations
//
//*****************************************************************************
#define TIMER_1_BASE CPUTIMER1_BASE
void TIMER_1_init();
#define TIMER_0_BASE CPUTIMER0_BASE
void TIMER_0_init();
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

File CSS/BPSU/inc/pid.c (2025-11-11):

/*
 * pid.c
 *
 *  Created on: Apr 8, 2025
 *      Author: Daniel
 */

#include "pid.h"
#include "driverlib.h"
#include "board.h"

// External variables
extern float VMain;
extern float VBatt;
extern float VCurr;
extern float VRef;
extern float IBatt;

PIDControl_t IBattFast = {.value = 0, .ref = 0, .error = 0, .error_old = 0, .Kp = 0.15, .Ki = 0.01, .output = 0.7, .min = 0.0, .max = 1.0};
PIDControl_t IBattSlow = {.value = 0, .ref = 0, .error = 0, .error_old = 0, .Kp = 0.15, .Ki = 0.01, .output = 0, .min = 0.0, .max = 1.0};
PIDControl_t IBattReg = {.value = 0, .ref = 0, .error = 0, .error_old = 0, .Kp = 0.15, .Ki = 0.01, .output = 0, .min = 0.0, .max = 1.0};

PIDControl_t VBuckReg = {.value = 0, .ref = 4.0, .error = 0, .error_old = 0, .Kp = 3.5, .Ki = 0.15, .output = 0, .min = -1.0, .max = 1.0};

PIDControl_t VBoostFast = {.value = 0, .ref = 5.0, .error = 0, .error_old = 0, .Kp = 40, .Ki = 1, .output = 6.0, .min = -1.0, .max = 6.0};
PIDControl_t VBoostSlow = {.value = 0, .ref = 5.0, .error = 0, .error_old = 0, .Kp = 10, .Ki = 0.1, .output = 0, .min = -1.0, .max = 6.0};
PIDControl_t VBoostReg = {.value = 0, .ref = 5.0, .error = 0, .error_old = 0, .Kp = 10, .Ki = 0.1, .output = 0, .min = -1.0, .max = 6.0};

//PIDControl_t VBuckSimple = {.value = 0, .ref = 0, .error = 0, .error_old = 0, .Kp = 0.01, .Ki = 0.001, .output = 0, .min = 0.0, .max = 1.0};

#pragma CODE_SECTION(PID, ".TI.ramfunc")
float PID(float ref, float value, PIDControl_t* pid) {
    // Store values (for debug purposes)
    pid->ref = ref;
    pid->value = value;
    // Error compared to the reference
    pid->error = ref - value;
    // Integrate
    pid->output += pid->Kp * (pid->error - pid->error_old) + pid->Ki * pid->error;
    // Store old error (to calculate change/derivate)
    pid->error_old = pid->error;
    // Saturate output
    pid->output = __fsat(pid->output, pid->max, pid->min);
    // return saturated output
    return pid->output;
}

// Dummy voltage to voltage based pwm control
/*
#pragma CODE_SECTION(BuckSimple, ".TI.ramfunc")
void BuckSimple(float vRef) {
    float pwm = PID(vRef, VBatt, &VBuckSimple);
    EPWM_setCounterCompareValue(GATE_PWM_BASE, EPWM_COUNTER_COMPARE_A, (1.0-pwm) * TBPRD);
}
*/

// DCDC converter current control, used by Buck and Boost voltage control (and current limiting)
#pragma CODE_SECTION(ControlCurrent, ".TI.ramfunc")
void ControlCurrent(float iRef) {
    float pwm = PID(iRef, IBatt, &IBattReg);
    EPWM_setCounterCompareValue(GATE_PWM_BASE, EPWM_COUNTER_COMPARE_A, (1.0-pwm) * TBPRD);
}

// DCDC converter Buck (voltage decreasing) mode
#pragma CODE_SECTION(ControlBuck, ".TI.ramfunc")
void ControlBuck() {
    float current = PID(VBuckReg.ref, VBatt, &VBuckReg);
    ControlCurrent(current);
}

// DCDC converter Boost (voltage increasing) mode
#pragma CODE_SECTION(ControlBoost, ".TI.ramfunc")
void ControlBoost() {
    float current = PID(VBoostReg.ref, VMain, &VBoostReg);
    float dutyCycle = -IBattReg.output;
    //float dutyCycle = -1 * VBatt / VMain;
    ControlCurrent(current * dutyCycle);
}

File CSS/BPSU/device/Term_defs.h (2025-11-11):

#ifndef _TERM_DEFS_
#define _TERM_DEFS_

/*-----------------------------------------------------------------------------*/

#define MAX_CHAR_LEN      11        /*!< Maximal length of the variable name */
#define MAXCH_TABNAME     11        /*!< Maximal length of the tab name */
#define MAXCH_DSPNAME     11        /*!< Maximal length of the DSP name */
#define MAXCH_UNIT         5        /*!< Maximal length of the unit string */

#define MON_MAXTABS        2 /** First tab is not visible */

#define TYP_32BIT       0x00        /*!< Variable is 32bit */
#define TYP_16BIT       0x01        /*!< Variable is 16bit */
#define TYP_SIGNED      0x00        /*!< Variable is signed */
#define TYP_UNSIGNED    0x02        /*!< Variable is unsigned */
#define TYP_IQ(n)       (4*n)       /*!< Variable is _IQn type 0-30.*/
#define TYP_HEX         0x80        /*!< Variable is hexadecimal */
#define TYP_FLOAT       0x100       /*!< Variable is floating type */
#define TYP_ENWR        0x200       /*!< Variable is writable */
#define TYP_SHIFT(n)    (0x400 * n) /*!< Variable is needs to be shifted with n for the recorder n <= 16 */

#define TYP_U32         (TYP_UNSIGNED+TYP_32BIT)
#define TYP_S32         (TYP_SIGNED+TYP_32BIT)
#define TYP_U16         (TYP_UNSIGNED+TYP_16BIT)
#define TYP_S16         (TYP_SIGNED+TYP_16BIT)

#define TYP_IQ_MASK     0x7C        /*!< Mask to get IQ number */
#define TYP_IQ_SHIFT    2           /*!< Shift to get IQ number */
#define TYP_SIGN_MASK   0x02        /*!< Mask to get the sign of variable */
#define TYP_BIT_MASK    0x01        /*!< Mask to get the type for the variable (bit nr) */
#define TYP_DISP_MASK   (4*0x1F)    /*!< Mask to get the Variable is 32bit */
#define TYP_SHIFT_MASK  0x3C00      /*!< Mask to get the shifting */
#define TYP_SH_SHIFT    10          /*!< Shifting used to get the shift values */
#define TYP_SH_IQ       2           /*!< Shifting used to get the iq values */


#define CA_U32(ad) (uint32_t)(&ad)  /*!< Macro to generate the address to store it in the flash of the processor */

typedef struct {
  uint8_t   name[MAX_CHAR_LEN + 1]; /*!< name of the variable, it is uint8_t type, but stored as if it were uint16_t type */
  uint16_t  unit;                   /*!< unit for the given variable */
  uint16_t  type;                   /*!< type of variable (bit length, display format, R/RW */
  uint32_t  ptr;                    /*!< address of the variable */
  uint32_t  pmax;                   /*!< pointer to the maximal value of the variable valid, if writable */
  uint32_t  pmin;                   /*!< pointer to the minimal value of the variable valid, if writable */
} var_type;

extern const var_type vars_misc[];

#define UNIT_NONE      0
#define UNIT_A         1
#define UNIT_V         2
#define UNIT_KVA       3
#define UNIT_KW        4
#define UNIT_S         5
#define UNIT_H         6
#define UNIT_NM        7
#define UNIT_KWH       8
#define UNIT_HZ        9
#define UNIT_VS       10
#define UNIT_NA       11
#define UNIT_W        12
#define UNIT_Var      13
#define UNIT_VA       14
#define UNIT_RADPS    15
#define UNIT_DI       16
#define UNIT_RAD      17
#define UNIT_VER      18
#define UNIT_DEGC     19
#define UNIT_PERC     20
#define UNIT_BITF     21
#define UNIT_100MS    22
#define UNIT_MS       23
#define UNIT_MA       24

#define MAXCH_DESC 16               /*!< length of error descriptors in characters */
typedef struct {
  uint8_t desc_number;              /*!< descriptor number - eg error code */
  uint8_t desc_text[MAXCH_DESC+1];  /*!< descriptor text */
} desc_type;

#define LEN_ERR_DESC    15
#define LEN_MAINSM_DESC 5

extern const desc_type error_descriptor[LEN_ERR_DESC],mainsm_descriptor[LEN_MAINSM_DESC];

extern const uint8_t tabtitle[MON_MAXTABS][MAXCH_TABNAME+1];
extern uint16_t tabsize[MON_MAXTABS];
extern const var_type* tabptr[MON_MAXTABS];
extern const uint8_t units[25][MAXCH_UNIT+1];

/* Term_defs functions */
void InitTermVars();

#endif

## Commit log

2024-09-26 Project created
    [UPS.PcbDoc, UPS.PrjPcb, UPS.SchDoc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]
2024-10-14 Added basic circuits
    And some alternatives
    [Battery.SchDoc, BuckBoost.SchDoc, UPS.PcbDoc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]
2024-10-14 Power Path + LDO
    [UPS.SchDoc, UPS_Schlib.SchLib]
2024-10-15 New gate driver + low side driver
    [Battery.SchDoc, BuckBoost.SchDoc, UPS.SchDoc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]
2024-10-16 Sch redesign, measurements
    [Battery.SchDoc, BuckBoost.SchDoc, Communication.SchDoc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]
2024-10-17 Created main sheet
    [BuckBoost.SchDoc, Communication.SchDoc, Generic_PcbLib.PcbLib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]
2024-10-26 Analog 3v3 and GND
    [BuckBoost.SchDoc, Communication.SchDoc, Main.SchDoc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]
2024-10-30 New gate driver circuit
    Deleted aux driver
    [BuckBoost.SchDoc, Communication.SchDoc, Main.SchDoc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]
2024-10-31 PCB Progress
    [BuckBoost.SchDoc, Communication.SchDoc, Main.SchDoc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]
2024-11-01 Added jumpers, removed battery
    Smaller PCB
    [BuckBoost.SchDoc, Communication.SchDoc, Power.SchDoc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]
2024-11-02 Modified REF voltage and current read
    [BuckBoost.SchDoc, UPS_Schlib.SchLib]
2024-11-02 1206 4-wire kelvin footprints
    [BuckBoost.SchDoc, Power.SchDoc, UPS.PcbDoc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]
2024-11-03 Added line capacitors
    [BuckBoost.SchDoc, Communication.SchDoc, Power.SchDoc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]
2024-11-03 Battery protection turn on
    [Power.SchDoc]
2024-11-03 Modified connectors
    [BuckBoost.SchDoc, Communication.SchDoc, Power.SchDoc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]
2024-11-03 Separeted grounds
    [BuckBoost.SchDoc, Communication.SchDoc, Power.SchDoc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]
2024-11-03 Added test points
    [BuckBoost.SchDoc, Communication.SchDoc, Power.SchDoc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]
2024-11-03 Added even more capacitors
    [BuckBoost.SchDoc, Communication.SchDoc, Main.SchDoc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]
2024-11-03 Routed gate driver
    [BuckBoost.SchDoc, Communication.SchDoc, Power.SchDoc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]
2024-11-04 Routed current sensor
    [BuckBoost.SchDoc]
2024-11-05 Routed battery protection
    [Main.SchDoc, UPS_Schlib.SchLib]
2024-11-05 Added mounting holes
    [BuckBoost.SchDoc, Communication.SchDoc, Main.SchDoc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]
2024-11-05 Routed usb-uart bridge
    [Communication.SchDoc]
2024-11-05 Routed power path switch
    [Power.SchDoc]
2024-11-05 uC capacitors
    [Power.SchDoc, uC.SchDoc]
2024-11-05 Routed uC
    [uC.SchDoc]
2024-11-06 Finished most of the routing
    Finished test points
    [BuckBoost.SchDoc, Communication.SchDoc, Main.SchDoc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]
2024-11-06 Routed all leds
2024-11-06 Cleaned up silkscreen
    [Power.SchDoc]
2024-11-06 Moved connectors closer to the edge
    [Power.SchDoc]
2024-11-06 Cleared design rule check
    Also added some thermal vias
    [BuckBoost.SchDoc, Power.SchDoc, UPS_Schlib.SchLib]
2024-11-06 Added silkscreen texts
    And bongo cat :3
2024-12-01 Improved schematic layout
    [150060VS75000.stp, 1736036.stp, 694106301002.stp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]
2024-12-01 Refactor file structure
    [150060VS75000.stp, 1736036.stp, 694106301002.stp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]
2024-12-06 Added files to folders and documentation
    [BuckBoost.SchDoc, Communication.SchDoc, MUCI.obj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]
2025-06-02 Moved hw files
    [150060VS75000.stp, 1736036.stp, 694106301002.stp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]
2025-06-02 Deleted old hw files
    [150060VS75000.stp, 1736036.stp, 694106301002.stp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]
2025-11-11 Updated code base from local project
    [MUCI.obj, MUCI_CRCGenerator.obj, MUCI_MonitorCommands.obj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]
